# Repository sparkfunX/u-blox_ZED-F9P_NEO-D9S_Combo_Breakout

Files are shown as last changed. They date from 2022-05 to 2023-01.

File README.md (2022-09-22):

# SparkX u-blox ZED-F9P NEO-D9S Combo Breakout

<p align="center">
  <a href="https://github.com/sparkfunX/u-blox_ZED-F9P_NEO-D9S_Combo_Breakout/issues" alt="Issues">
    </a>
  <a href="https://github.com/sparkfunX/u-blox_ZED-F9P_NEO-D9S_Combo_Breakout/actions" alt="Actions">
    </a>
  <a href="https://github.com/sparkfunX/u-blox_ZED-F9P_NEO-D9S_Combo_Breakout/blob/main/LICENSE.md" alt="License">
    </a>
  <a href="https://twitter.com/intent/follow?screen_name=sparkfun">
    </a>
</p>

SparkX u-blox ZED-F9P NEO-D9S Combo Breakout (https://www.sparkfun.com/products/20167)

*[SparkX u-blox ZED-F9P NEO-D9S Combo Breakout (SPX-20167)](https://www.sparkfun.com/products/20167)*

The [SparkX u-blox ZED-F9P NEO-D9S Combo Breakout (SPX-20167)](https://www.sparkfun.com/products/20167) combines the u-blox ZED-F9P multi-band high precision GNSS module
with the NEO-D9S L-band GNSS correction data receiver. With a clear view of the sky, especially a clear view to the South, this combo breakout will deliver centimeter-level
accuracy positioning without needing separate RTK or NTRIP corrections.

The Combo Breakout is designed to work with u-blox's PointPerfect L-band satellite GNSS augmentation service, which provides homogeneous coverage in contiguous USA and Europe.

### Important Note:

u-blox provides products and services to "B2B Customers". Only business customers are eligible to register for a Thingstream (PointPerfect) account. You may be required to demonstrate that the use of the combo breakout is in relation to your trade, business, craft or profession. u-blox products and services are not intended for individual consumer use.

## Repository Contents

* **[/docs](/docs/)** - Online documentation files
    * [board_files](/docs/board_files/) - Files for the product design
        * [Eagle design files](/docs/board_files/ZED-F9P_NEO-D9S_Combo_x02.zip) (.zip)
        * [Schematic](/docs/board_files/Schematic.pdf) (.pdf)
        * [Dimensions](/docs/board_files/Dimensions.png) (.png)
    * [img/hookup_guide/](/docs/img/hookup_guide/) - Images for hookup guide documentation
* **[/Hardware](/Hardware/)** - Eagle design files (.brd, .sch)

## Documentation

* **[Hookup Guide (mkdocs)](https://sparkfunx.github.io/u-blox_ZED-F9P_NEO-D9S_Combo_Breakout)** - Hookup guide for the SparkX u-blox ZED-F9P NEO-D9S Combo Breakout hosted by GitHub pages.

## Product Versions

* [SPX-20167](https://www.sparkfun.com/products/20167) - Initial SparkX Release

## License Information

This product is _**open source**_! 

Please review the LICENSE.md file for license information. 

If you have any questions or concerns on licensing, please contact technical support on our [SparkFun forums](https://forum.sparkfun.com/viewforum.php?f=152).

Distributed as-is; no warranty is given.

- Your friends at SparkFun.

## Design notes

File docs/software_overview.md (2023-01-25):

## Software Overview

There are three key steps to be able to achieve centimeter positioning accuracy using the ZED-F9P NEO-D9S Combo Breakout:

* Register with u-blox Thingstream and sign up for a PointPerfect L-band plan (data stream)
* Configure the NEO-D9S to receive the u-blox PointPerfect correction data stream
* Configure the ZED-F9P with encryption key(s) so it can decrypt and use the correction data

By default, the Combo Breakout is configured such that the correction data is passed from the NEO to the ZED using the UART2 interface.
However, it is also possible to read the correction data from the NEO and push (write) it to the ZED using I<sup>2</sup>C.

## Thingstream and PointPerfect

[Thingstream](https://www.u-blox.com/en/product/thingstream) is u-blox service delivery platform for IoT Communication-as-a-Service, IoT Security-as-a-Service and IoT Location-as-a-Service.

[PointPerfect](https://www.u-blox.com/sites/default/files/PointPerfect_ProductSummary_UBX-21024758.pdf) is u-blox GNSS augmentation service which is designed to provide high-precision GNSS corrections to suitable receivers to provide decimeter-level location accuracy.

PointPerfect data is delivered through Thingstream. The first step is to [register with Thingstream](https://portal.thingstream.io/register) and then request an L-Band plan:

<center>
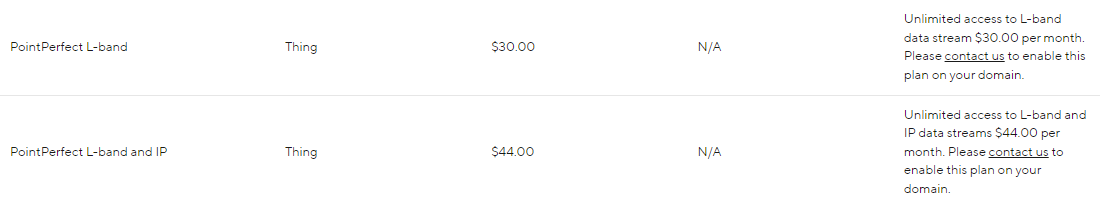
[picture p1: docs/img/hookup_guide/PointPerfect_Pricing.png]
PointPerfect Pricing
<br>
*PointPerfect pricing (correct at Sept. 14th 2022). (Click to enlarge)*
</center>

You can find the current pricing on [u-blox portal](https://portal.thingstream.io/pricing). Select **IoT Location-as-a-Service** and then **PointPerfect**.

You may need to [contact u-blox](mailto:support@thingstream.io) first, to enable the option to purchase an L-Band plan through your Thingstream account.

The **PointPerfect L-band** plan provides unlimited access to the L-band satellite correction data stream (via the NEO-D9S).

If you have an internet connection, you can also receive PointPerfect corrections via IP (MQTT). The **PointPerfect L-band and IP** plan may be a better choice if
you think you may want to receive correction data via both satellite and Internet.

Once L-band permissions are enabled on your Thingstream account, you will be able to add a new L-band Location Thing and view its credentials:

* [Login to Thingstream](https://portal.thingstream.io/)
* Select **Location Services** and then **Location Things**
* The **Add Location Thing** button (top right) will allow you to select and activate an L-Band plan
* Once your L-band plan is active, you will be able to monitor your **Activity** and view your **Credentials** via the appropriate tabs

u-blox have written a [comprehensive application note](https://www.u-blox.com/sites/default/files/documents/NEO-D9S_ZED-F9_Config_SPARTN_AppNote_UBX-22008160.pdf) which
describes in detail: the configuration of both NEO and ZED; and how to interpret the expiry date for the L-band encryption keys. In the following sections, we describe how
to configure the NEO and ZED using our [u-blox GNSS Arduino Library](https://github.com/sparkfun/SparkFun_u-blox_GNSS_v3).

## NEO-D9S Configuration

The first step is to declare the **`SFE_UBLOX_GNSS`** object. Like most Arduino sketches, this is done at a global scope (after the include file declaration), not within the ```setup()``` or ```loop()``` functions. 

```C++
#include <SparkFun_u-blox_GNSS_v3.h> //http://librarymanager/All#SparkFun_u-blox_GNSS_v3
SFE_UBLOX_GNSS myLBand; // NEO-D9S
```

Within ```setup()``` we then need to start (initialize) communiation with the NEO-D9S.
The NEO-D9S has a default I<sup>2</sup>C address of 0x43 and so we need to provide that when calling the ```begin``` method:

```C++
  Wire.begin(); //Start I2C

  while (myLBand.begin(Wire, 0x43) == false) //Connect to the u-blox NEO-D9S using Wire port. The D9S default I2C address is 0x43 (not 0x42)
  {
    Serial.println(F("u-blox NEO-D9S not detected at default I2C address. Please check wiring."));
    delay(2000);
  }
  Serial.println(F("u-blox NEO-D9S connected"));

```

The NEO-D9S needs to be configured so it can receive the PointPerfect correction stream. The configuration items are: 

| Configuration item | Default value |
| :--- | :---- |
| CFG-PMP-CENTER_FREQUENCY | 1539812500 Hz |
| CFG-PMP-SEARCH_WINDOW | 2200 Hz |
| CFG-PMP-USE_SERVICE_ID | 1 (true)|
| CFG-PMP-SERVICE_ID | 50821 |
| CFG-PMP-DATA_RATE | 2400 (B2400) bps |
| CFG-PMP-USE_DESCRAMBLER | 1 (true) |
| CFG-PMP-DESCRAMBLER_INIT | 23560 |
| CFG-PMP-USE_PRESCRAMBLING | 0 (false) |
| CFG-PMP-UNIQUE_WORD | 0xe15ae893e15ae893 |

The centre frequency varies depending on which satellite is broadcasting corrections for your geographical area.
The frequency for the USA is different to that for Europe:

The up-to-date frequencies are distributed via the MQTT **/pp/frequencies/Lb** topic. At the time of writing, they are (in MHz):

```C++
{
  "frequencies": {
    "us": {
      "current": {
        "value": "1556.29"
      }
    },
    "eu": {
      "current": {
        "value": "1545.26"
      }
    }
  }
}
```

We can add those to the code as follows:

```C++
const uint32_t myLBandFreq = 1556290000; // Uncomment this line to use the US SPARTN 1.8 service
//const uint32_t myLBandFreq = 1545260000; // Uncomment this line to use the EU SPARTN 1.8 service
```

The code to configure the NEO-D9S is as follows. Note that the **`UBLOX_CFG_PMP_USE_SERVICE_ID`**, **`UBLOX_CFG_PMP_SERVICE_ID`** and **`UBLOX_CFG_PMP_DESCRAMBLER_INIT`**
also need to be changed.

```C++
  uint8_t ok = myLBand.setVal(UBLOX_CFG_PMP_CENTER_FREQUENCY,  myLBandFreq); // Default 1539812500 Hz
  if (ok) ok = myLBand.setVal(UBLOX_CFG_PMP_SEARCH_WINDOW,     2200);        // Default 2200 Hz
  if (ok) ok = myLBand.setVal(UBLOX_CFG_PMP_USE_SERVICE_ID,    0);           // Default 1 
  if (ok) ok = myLBand.setVal(UBLOX_CFG_PMP_SERVICE_ID,        21845);       // Default 50821
  if (ok) ok = myLBand.setVal(UBLOX_CFG_PMP_DATA_RATE,         2400);        // Default 2400 bps
  if (ok) ok = myLBand.setVal(UBLOX_CFG_PMP_USE_DESCRAMBLER,   1);           // Default 1
  if (ok) ok = myLBand.setVal(UBLOX_CFG_PMP_DESCRAMBLER_INIT,  26969);       // Default 23560
  if (ok) ok = myLBand.setVal(UBLOX_CFG_PMP_USE_PRESCRAMBLING, 0);           // Default 0
  if (ok) ok = myLBand.setVal(UBLOX_CFG_PMP_UNIQUE_WORD,       16238547128276412563ull); // 0xE15AE893E15AE893
```

Finally, we need to ensure that the UART2 port is set correctly. We need to:

* Change the baud rate to 38400 - to match the ZED-F9P's baud rate
* Ensure that the **UBX** protocol is enabled for output on UART2
* Enable the **RXM PMP** message on UART2
    * The **RXM PMP** message contains the **SPARTN** correction data in **UBX** format
* Perform a restart (software reset) so that the NEO-D9S starts using the new configuration items

```C++
  if (ok) ok = myLBand.setVal(UBLOX_CFG_UART2_BAUDRATE,           38400); // match baudrate with ZED default
  if (ok) ok = myLBand.setVal(UBLOX_CFG_UART2OUTPROT_UBX,         1);     // Enable UBX output on UART2
  if (ok) ok = myLBand.setVal(UBLOX_CFG_MSGOUT_UBX_RXM_PMP_UART2, 1);     // Output UBX-RXM-PMP on UART2
  
  Serial.print(F("L-Band configuration: "));
  if (ok)
    Serial.println(F("OK"));
  else
    Serial.println(F("NOT OK!"));

  myLBand.softwareResetGNSSOnly(); // Do a restart
```

Once the NEO-D9S has aquired the signal from the satellite, it will start outputting **PMP** correction messages to the ZED-F9P on UART2.

## ZED-F9P Configuration

We need to declare a second **`SFE_UBLOX_GNSS`** object for the ZED-F9P. Again, this is done at a global scope (after the include file declaration), not within the ```setup()``` or ```loop()``` functions. 

```C++
SFE_UBLOX_GNSS myGNSS; // ZED-F9P
```

Within ```setup()``` we need to start (initialize) communiation with the ZED-F9P:

```C++
  while (myGNSS.begin() == false) //Connect to the u-blox module using Wire port and the default I2C address (0x42)
  {
    Serial.println(F("u-blox GNSS module not detected at default I2C address. Please check wiring."));
    delay(2000);
  }
  Serial.println(F("u-blox GNSS module connected"));
```

We then need to:

* Make sure the ZED-F9P's UART2 port is configured to accept the PMP correction data
* Tell the ZED-F9P to use FIXED carrier solutions when possible (this is the default setting)
* Tell the ZED-F9P to accept L-band PMP as a correction source

```C++
          ok = myGNSS.setI2CInput(COM_TYPE_UBX | COM_TYPE_NMEA | COM_TYPE_SPARTN); //Be sure SPARTN input is enabled
  if (ok) ok = myGNSS.setDGNSSConfiguration(SFE_UBLOX_DGNSS_MODE_FIXED); // Set the differential mode - ambiguities are fixed whenever possible
  if (ok) ok = myGNSS.setVal8(UBLOX_CFG_SPARTN_USE_SOURCE, 1); // use LBAND PMP message
```

The final piece of the puzzle is to provide the ZED-F9P with the keys it needs to decrypt the encrypted SPARTN (PMP) corrections.

The ZED-F9P can hold two dynamic keys: the current key; and the next key. We also need to tell it when each key is valid from, so it knows when to switch to the next key.

You can find the current and next keys in the **`Location Services \ Location Things \ Thing Details \ Credentials`** tab in Thingstream:

<center>
L-band Dynamic Keys<br>
*PointPerfect L-band dynamic keys. (Click to enlarge)*
</center>

The ZED-F9P actually needs to know when the keys are valid **from**, rather than when they expire. Each key is walid for four weeks, so we need to work backwards 4 weeks from the expiry date.

The current key expires at midnight (UTC) at the end of Friday September 23rd. This means it became valid 4 weeks earlier at midnight (UTC) on August 27th:

<center>
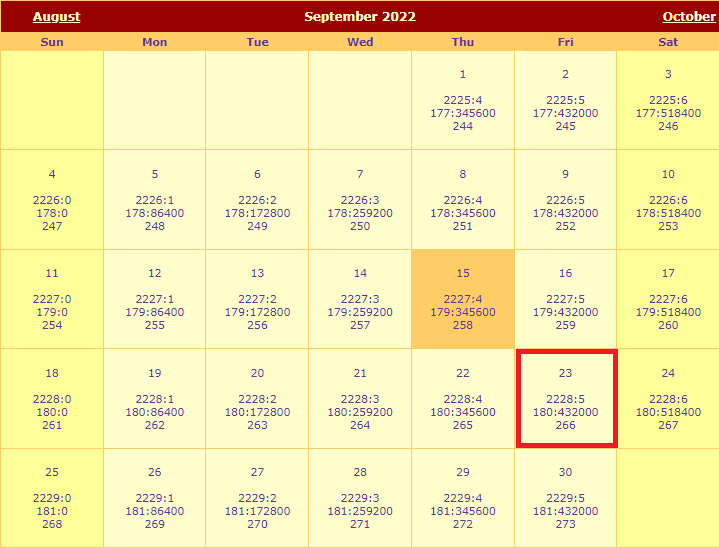
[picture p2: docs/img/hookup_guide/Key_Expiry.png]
Dynamic Key expiry
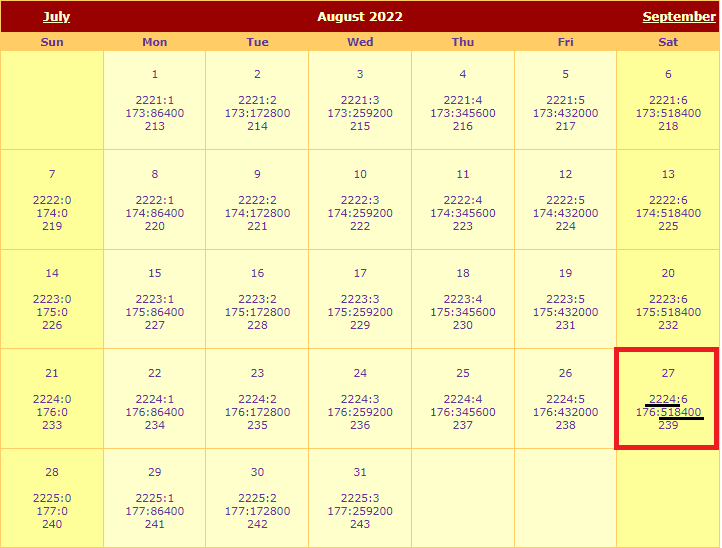
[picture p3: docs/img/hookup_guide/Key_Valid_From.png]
Dynamic Key valid from
  <br>
*Dynamic Key: Expiry and Valid From dates. (Click to enlarge)*
</center>

Using the website recommended in the u-blox Application Note:

**http://navigationservices.agi.com/GNSSWeb**

we can see that the key became valid during GPS week **2224**, at time-of-week **518400**.

We can use the Arduino Library **`setDynamicSPARTNKey`** method to configure a single key:

```C++
  if (ok) ok = myGNSS.setDynamicSPARTNKey(16, 2224, 518400, "500--------------------------177");

  Serial.print(F("GNSS: configuration "));
  if (ok)
    Serial.println(F("OK"));
  else
    Serial.println(F("NOT OK!"));
```

Alternately, we can set both the current key and the next key together using **`setDynamicSPARTNKeys`**. The next key becomes valid during GPS week **2228**:

```C++
  if (ok) ok = myGNSS.setDynamicSPARTNKeys(16, 2224, 518400, "500--------------------------177", 16, 2228, 518400, "582--------------------------a7d");
```

The keys can also be retrieved using MQTT. We have an [Arduino Library example](https://github.com/sparkfun/SparkFun_u-blox_GNSS_v3/tree/main/examples/NEO-D9S_and_NEO-D9C/Example6_PMP_with_L-Band_Keys_via_MQTT)
which shows how to retrieve the keys from the L-band + IP key distribution topic **/pp/ubx/0236/Lb** . That topic provides the keys in UBX (binary) format, ready to be pushed to the ZED.

The keys are also available in human-readable JSON format from the MQTT topic **/pp/key/Lb** . But note that that topic provides the **valid from** in Unix epoch format,
in milliseconds, excluding the 18 leap seconds since GPS time started!

```C++
{
  "dynamickeys": {
    "current": {
      "start": "1661558382000",
      "duration": "2419199999",
      "value": "500--------------------------177"
    },
    "next": {
      "start": "1663977582000",
      "duration": "2419199999",
      "value": "582--------------------------a7d"
    }
  }
}
```

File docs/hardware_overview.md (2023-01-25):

## Hardware Overview

<center>
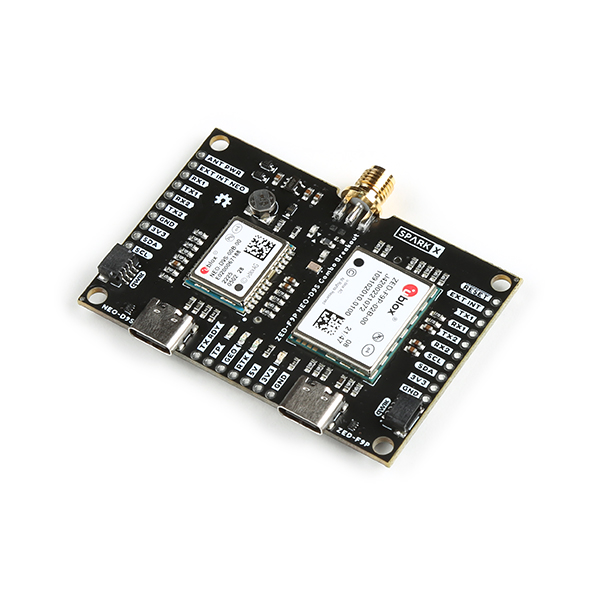
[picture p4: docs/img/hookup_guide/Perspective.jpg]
Combo Breakout PCB
<br>
*The Combo Breakout PCB. (Click to enlarge)*
</center>

The u-blox ZED-F9P NEO-D9S Combo Breakout is a sophisticated yet compact GNSS board. The following is a summary of its features and functions:

* **`ZED-F9P`** - the ZED-F9P is a top-of-the-line module for high accuracy GNSS and GPS location solutions
    * Concurrent reception of GPS, GLONASS, Galileo and BeiDou
    * Multi-band RTK with fast convergence times and reliable performance
    * Centimeter-level accuracy in a small and energy-efficient module

<center>
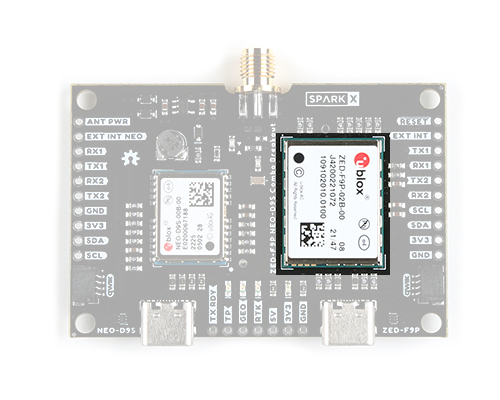
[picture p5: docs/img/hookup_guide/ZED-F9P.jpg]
ZED-F9P
<br>
*The ZED-F9P GNSS module. (Click to enlarge)*
</center>

* **`NEO-D9S`** - the NEO-D9S is a satellite data receiver for L-band correction broadcast
    * The NEO-D9S can be configured for use with a variety of L-band correction services including u-blox's PointPerfect service
    * It decodes the satellite transmission and outputs a correction stream directly to the ZED-F9P via UART2

<center>
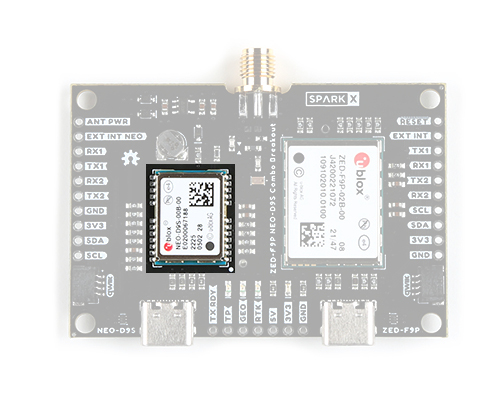
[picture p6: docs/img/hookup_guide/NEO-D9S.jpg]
NEO-D9S
<br>
*The NEO-D9S correction data receiver. (Click to enlarge)*
</center>

* **`UART2 TX and RX`** - the ZED-F9P and NEO-D9S UART2 TX and RX are interconnected (crossed-over) to allow the NEO to feed corrections directly to the ZED
    * The UART2 pins can be isolated if required by opening the **TX2** and **RX2** jumpers
    * Using UART2 to pass the correction data is recommended, but is optional. You can use UART1 or I<sup>2</sup>C instead if you want to. Our u-blox Arduino Library has an [example](https://github.com/sparkfun/SparkFun_u-blox_GNSS_v3/tree/main/examples/NEO-D9S_and_NEO-D9C/Example2_LBand_Corrections_with_NEO-D9S) which shows how to read the correction data from the NEO-D9S and push it to the ZED-F9P using I<sup>2</sup>C.

<center>
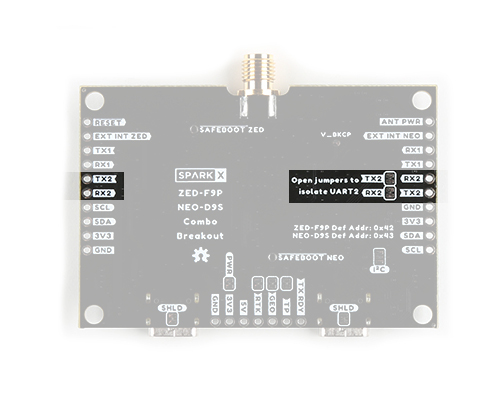
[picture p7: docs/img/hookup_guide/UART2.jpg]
UART2
<br>
*The UART2 connections. (Click to enlarge)*
</center>

* **`Antenna Power Divider`** - the breakout has an on-board power divider (antenna splitter) to divide the satellite signals between the ZED and the NEO
    * The connector is SMA female (standard polarity)
    * 3.3V power is provided for an active antenna

<center>
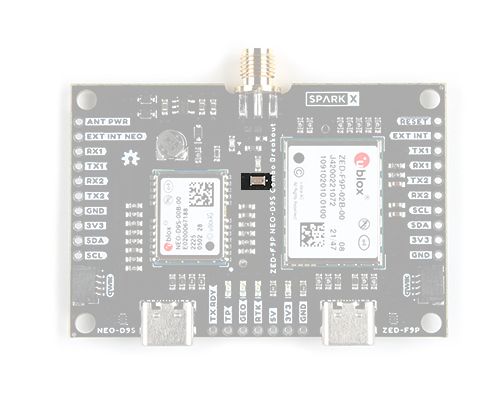
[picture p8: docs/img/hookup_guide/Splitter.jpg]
Splitter
<br>
*The antenna splitter (power divider). (Click to enlarge)*
</center>

* **`Dual USB-C connections`** - one USB-C connector provides a direct connection to the ZED-F9P; the second provides a direct connection to the NEO-D9S
    * The board can be powered via either USB-C connector, or both
    * There is no on-board USB hub. Both ports can be connected simultaneously to the same computer, or different computers if desired

<center>
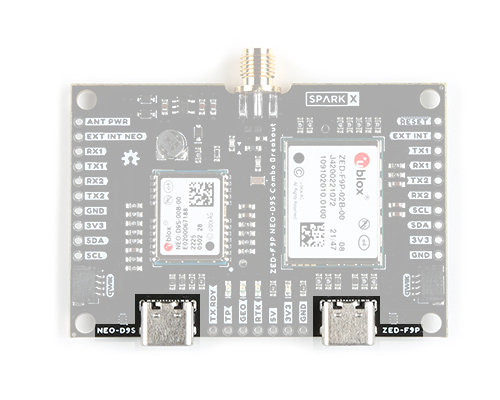
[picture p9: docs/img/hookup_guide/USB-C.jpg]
USB Connectors
<br>
*The two USB-C connectors. (Click to enlarge)*
</center>

* **`LED Indicators`** - the breakout has four LED indicators:
    * **3V3** Power
    * **RTK**: Off = No Carrier Solution; Flashing = Floating Solution; On = Fixed Solution
    * **GEO**: Geofence indication
    * **TP**: Timing Pulse (Pulse Per Second)
    * Each LED can be disabled by opening the corresponding split pad jumper on the bottom of the breakout

<center>
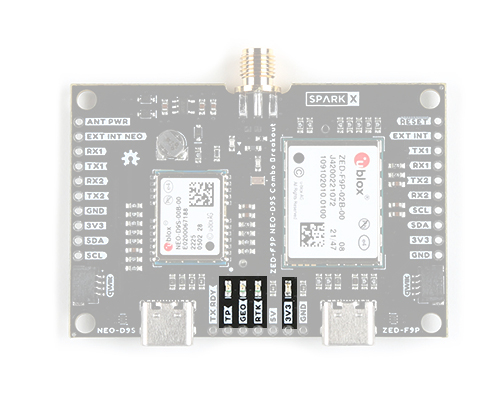
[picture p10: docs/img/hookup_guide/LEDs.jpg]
LEDs
<br>
*The LEDs. (Click to enlarge)*
</center>

* **`Dual Qwiic Connectors`** - the breakout has two Qwiic (I<sup>2</sup>C) connectors allowing the breakout to be daisy-chained into your Qwiic project

<center>
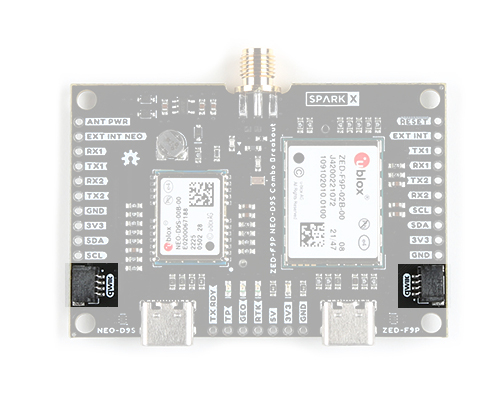
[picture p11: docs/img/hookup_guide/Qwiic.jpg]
Qwiic Connectors
<br>
*The two Qwiic connectors. (Click to enlarge)*
</center>

* **`Back-up Battery`** - a small rechargeable coin cell maintains the ZED-F9P battery-backed RAM while the power is disconnected

<center>
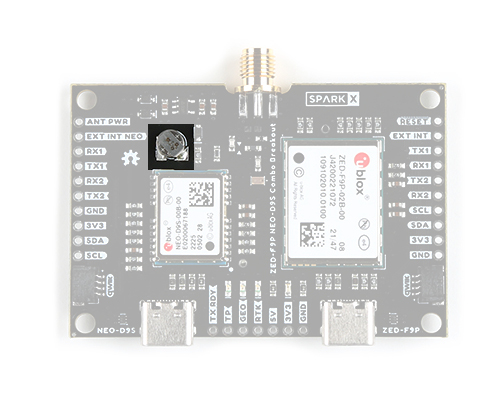
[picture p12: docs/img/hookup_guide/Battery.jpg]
Back-up Battery
<br>
*The rechargeable back-up battery. (Click to enlarge)*
</center>

* **`Full set of breakout pads`** - the breakout pads provide full access to the ZED-F9P and NEO-D9S pins 
    * I<sup>2</sup>C
    * UART1
    * UART2
    * External Interrupt
    * Reset
    * Safeboot
    * ZED-F9P: TX_RDY, TP, GEO, RTK
    * Power: 5V and 3.3V

<center>
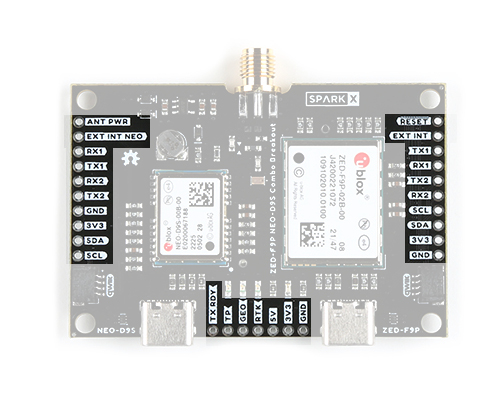
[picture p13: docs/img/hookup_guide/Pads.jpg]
Breakout Pads
<br>
*The breakout pads. (Click to enlarge)*
</center>

## Board Dimensions

The board dimensions are illustrated in the drawing below. The listed measurements are in inches. The four mounting holes are compatible with 4-40 UNC or M3.0 screws.

<center>
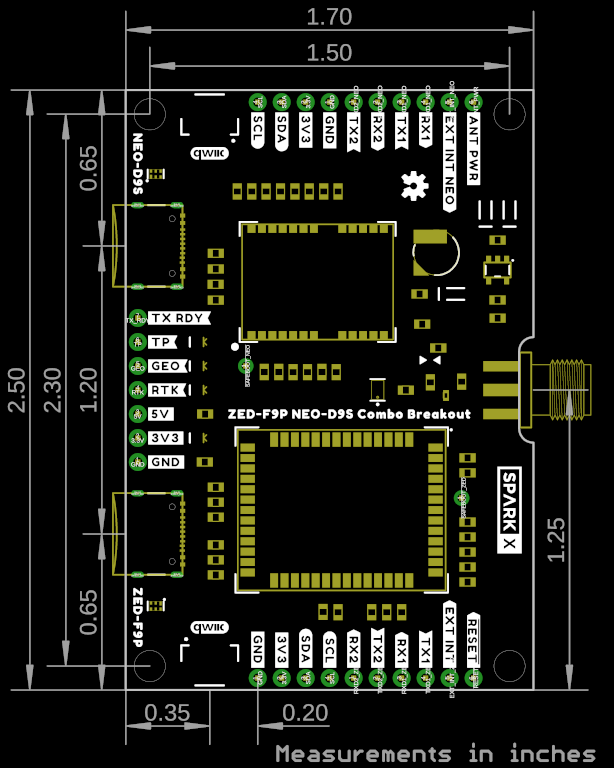
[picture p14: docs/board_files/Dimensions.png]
Board Dimensions
<br>
*Board dimensions. (Click to enlarge)*
</center>

## Left Edge Breakout Pads

With the SMA connector oriented to the 'top', the breakout pads down the left side of the board are:

<table style="font-size:12.25px; width:100%">
    <tr>
        <th style="text-align:center; vertical-align:middle; min-width:1rem;" width="20.0%">
            Pad
        </th>
        <th style="text-align:center; vertical-align:middle; min-width:4rem;" width="80.0%">
            Function
        </th>
    </tr>
    <tr>
        <td style="vertical-align:middle" align="center"><b>ANT_PWR</b></td>
        <td style="vertical-align:middle" align="center">External antenna power<br>Cut the <b>ANT_VCC</b> trace and install L1 to enable</td>
    </tr>
    <tr>
        <td style="vertical-align:middle" align="center"><b>EXT_INT_NEO</b></td>
        <td style="vertical-align:middle" align="center">Connected to the NEO-D9S EXT_INT pin</td>
    </tr>
    <tr>
        <td style="vertical-align:middle" align="center"><b>RX1</b></td>
        <td style="vertical-align:middle" align="center">NEO-D9S UART1 RX Pin</td>
    </tr>
    <tr>
        <td style="vertical-align:middle" align="center"><b>TX1</b></td>
        <td style="vertical-align:middle" align="center">NEO-D9S UART1 TX Pin</td>
    </tr>
    <tr>
        <td style="vertical-align:middle" align="center"><b>RX2</b></td>
        <td style="vertical-align:middle" align="center">NEO-D9S UART2 RX Pin<br>Connected to ZED-F9P TX2 (Open the <b>TX2</b> jumper to isolate)</td>
    </tr>
    <tr>
        <td style="vertical-align:middle" align="center"><b>TX2</b></td>
        <td style="vertical-align:middle" align="center">NEO-D9S UART2 TX Pin<br>Connected to ZED-F9P RX2 (Open the <b>RX2</b> jumper to isolate)</td>
    </tr>
    <tr>
        <td style="vertical-align:middle" align="center"><b>GND</b></td>
        <td style="vertical-align:middle" align="center">Power Ground (0V)</td>
    </tr>
    <tr>
        <td style="vertical-align:middle" align="center"><b>3V3</b></td>
        <td style="vertical-align:middle" align="center">3.3V Supply rail<br>Output of regulator U2 (Can also be used as a power input)</td>
    </tr>
    <tr>
        <td style="vertical-align:middle" align="center"><b>SDA</b></td>
        <td style="vertical-align:middle" align="center">I<sup>2</sup>C Data<br>Common to both ZED and NEO</td>
    </tr>
    <tr>
        <td style="vertical-align:middle" align="center"><b>SCL</b></td>
        <td style="vertical-align:middle" align="center">I<sup>2</sup>C Clock<br>Common to both ZED and NEO</td>
    </tr>
</table>

*For more details, users can reference the [schematic](./board_files/Schematic.pdf).*

## Right Edge Breakout Pads

With the SMA connector oriented to the 'top', the breakout pads down the right side of the board are:

<table style="font-size:12.25px; width:100%">
    <tr>
        <th style="text-align:center; vertical-align:middle; min-width:1rem;" width="20.0%">
            Pad
        </th>
        <th style="text-align:center; vertical-align:middle; min-width:4rem;" width="80.0%">
            Function
        </th>
    </tr>
    <tr>
        <td style="vertical-align:middle" align="center"><b>RESET</b></td>
        <td style="vertical-align:middle" align="center">Reset<br>Active low. Common to both ZED and NEO</td>
    </tr>
    <tr>
        <td style="vertical-align:middle" align="center"><b>EXT_INT</b></td>
        <td style="vertical-align:middle" align="center">Connected to the ZED-F9P EXT_INT pin</td>
    </tr>
    <tr>
        <td style="vertical-align:middle" align="center"><b>TX1</b></td>
        <td style="vertical-align:middle" align="center">ZED-F9P UART1 TX Pin</td>
    </tr>
    <tr>
        <td style="vertical-align:middle" align="center"><b>RX1</b></td>
        <td style="vertical-align:middle" align="center">ZED-F9P UART1 RX Pin</td>
    </tr>
    <tr>
        <td style="vertical-align:middle" align="center"><b>TX2</b></td>
        <td style="vertical-align:middle" align="center">ZED-F9P UART2 TX Pin<br>Connected to NEO-D9S RX2 (Open the <b>TX2</b> jumper to isolate)</td>
    </tr>
    <tr>
        <td style="vertical-align:middle" align="center"><b>RX2</b></td>
        <td style="vertical-align:middle" align="center">ZED-F9P UART2 RX Pin<br>Connected to NEO-D9S TX2 (Open the <b>RX2</b> jumper to isolate)</td>
    </tr>
    <tr>
        <td style="vertical-align:middle" align="center"><b>SCL</b></td>
        <td style="vertical-align:middle" align="center">I<sup>2</sup>C Clock<br>Common to both ZED and NEO</td>
    </tr>
    <tr>
        <td style="vertical-align:middle" align="center"><b>SDA</b></td>
        <td style="vertical-align:middle" align="center">I<sup>2</sup>C Data<br>Common to both ZED and NEO</td>
    </tr>
    <tr>
        <td style="vertical-align:middle" align="center"><b>3V3</b></td>
        <td style="vertical-align:middle" align="center">3.3V Supply rail<br>Output of regulator U2 (Can be used as a power input)</td>
    </tr>
    <tr>
        <td style="vertical-align:middle" align="center"><b>GND</b></td>
        <td style="vertical-align:middle" align="center">Power Ground (0V)</td>
    </tr>
</table>

*For more details, users can reference the [schematic](./board_files/Schematic.pdf).*

## Right Edge Breakout Pads

With the SMA connector oriented to the 'top', the breakout pads along the bottom edge of the board are:

<table style="font-size:12.25px; width:100%">
    <tr>
        <th style="text-align:center; vertical-align:middle; min-width:1rem;" width="20.0%">
            Pad
        </th>
        <th style="text-align:center; vertical-align:middle; min-width:4rem;" width="80.0%">
            Function
        </th>
    </tr>
    <tr>
        <td style="vertical-align:middle" align="center"><b>TX_RDY</b></td>
        <td style="vertical-align:middle" align="center">Indicates the ZED-F9P has data waiting in its I<sup>2</sup>C TX buffer</td>
    </tr>
    <tr>
        <td style="vertical-align:middle" align="center"><b>TP</b></td>
        <td style="vertical-align:middle" align="center">ZED-F9P Timing Pulse (Pulse Per Second)</td>
    </tr>
    <tr>
        <td style="vertical-align:middle" align="center"><b>GEO</b></td>
        <td style="vertical-align:middle" align="center">ZED-F9P Geofence indicator</td>
    </tr>
    <tr>
        <td style="vertical-align:middle" align="center"><b>RTK</b></td>
        <td style="vertical-align:middle" align="center">ZED-F9P RTK indication<br>High = No Carrier Solution. Square Wave = Floating Solution. Low = Fixed Solution</td>
    </tr>
    <tr>
        <td style="vertical-align:middle" align="center"><b>5V</b></td>
        <td style="vertical-align:middle" align="center">5V Power Rail<br>Can be used as a power input or output (from USB) (Diode protected)</td>
    </tr>
    <tr>
        <td style="vertical-align:middle" align="center"><b>3V3</b></td>
        <td style="vertical-align:middle" align="center">3.3V Supply rail<br>Output of regulator U2 (Can be used as a power input)</td>
    </tr>
    <tr>
        <td style="vertical-align:middle" align="center"><b>GND</b></td>
        <td style="vertical-align:middle" align="center">Power Ground (0V)</td>
    </tr>
</table>

*For more details, users can reference the [schematic](./board_files/Schematic.pdf).*

## Jumpers

!!! note
    <p>Never modified a jumper before? Check out our <a href="https://learn.sparkfun.com/tutorials/664">Jumper Pads and PCB Traces tutorial</a> for a quick introduction!</p>
    <p align="center">
        <a href="https://learn.sparkfun.com/tutorials/664">How to Work with Jumper Pads and PCB Traces<br>
        </a>
    </p>

There are multiple jumpers on the back of the board that can be used to modify how the board functions.

<center>
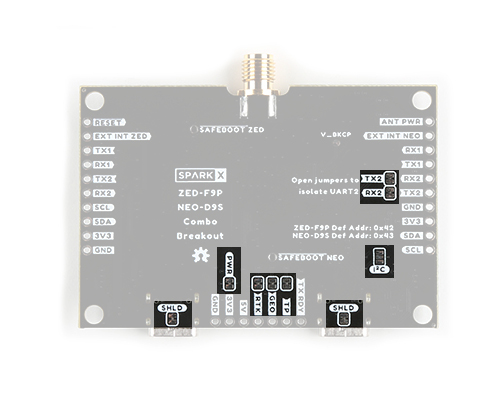
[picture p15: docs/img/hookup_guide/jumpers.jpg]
Jumpers
<br>
*The jumpers on the back of the function board. (Click to enlarge)*
</center>

* **TX2** - open this jumper to isolate NEO-D9S RX2 from ZED-F9P TX2
* **RX2** - open this jumper to isolate NEO-D9S TX2 from ZED-F9P RX2
    * By default, the NEO-D9S PMP (SPARTN) correction data stream is output directly from NEO-D9S TX2 to the ZED-F9P RX2
    * Opening this jumper will break that connection
    * Correction data can be read from the NEO-D9S and pushed to the ZED-F9P via I<sup>2</sup>C instead
* **I<sup>2</sup>C** - close this double jumper to connect additional pull-up resistors to I<sup>2</sup>C **SCL** and **SDA**. Not recommended
* **SHLD** - the two **SHLD** jumpers can be opened to isolate the USB-C connector shields from **GND**. Not recommended, but may help prevent EMI
* **PWR** - open this jumper to disable the Power LED
* **RTK** - open this jumper to disable the RTK LED
* **GEO** - open this jumper to disable the GEO LED
* **TP** - open this jumper to disable the TP (PPS) LED

## ANT PWR

By default, 3.3V active antenna power is provided on the SMA connector via the NEO-D9S **VCC_RF** output pin.
Power is delivered via a 10 Ohm resistor, to limit the current in case the antenna cable becomes shorted.

If your antenna requires a higher voltage (or current):

* Isolate **VCC_RF** by cutting the trace marked by the arrow symbols on the top of the PCB

<center>
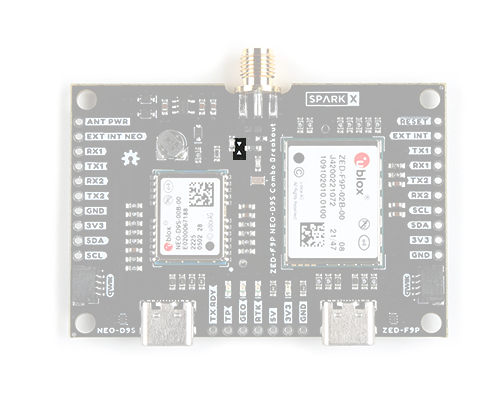
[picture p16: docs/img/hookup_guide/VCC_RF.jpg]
VCC_RF
<br>
*The VCC_RF trace. (Click to enlarge)*
</center>

* Install inductor L1 - using a 0603 inductor with impedance >500 Ohms at 1.5 GHz

<center>
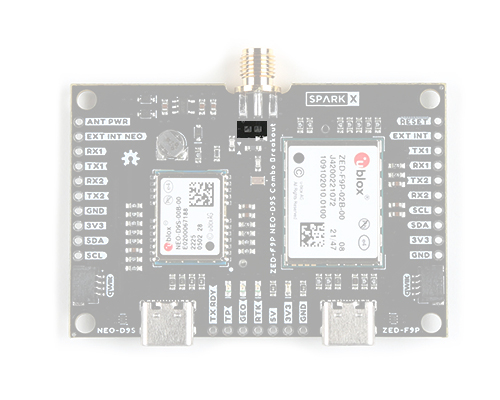
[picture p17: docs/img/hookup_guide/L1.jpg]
L1
<br>
*The position of L1. (Click to enlarge)*
</center>

* Inject a **clean** DC supply voltage between the **ANT PWR** breakout pad and **GND**

## SAFEBOOT

It _may_ be necessary to place the ZED-F9P or NEO-D9S into a "safe boot" state before applying a firmware upgrade.

If this becomes necessary:

* Disconnect power to the breakout board
* For the ZED-F9P: connect a jumper wire between the **SAFEBOOT ZED** test point and **GND**
* Reconnect the power
* Disconnect the jumper
* Upgrade the firmware using u-center

Repeat for the NEO-D9S using the **SAFEBOOT NEO** test point.

<center>
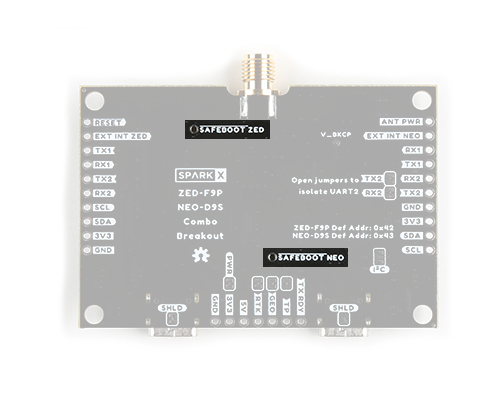
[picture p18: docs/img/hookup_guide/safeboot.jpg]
<br>
*The two SAFEBOOT test points. (Click to enlarge)*
</center>

## LED Indicators

The breakout has four LED indicators:

* **3V3** Power
* **RTK**: Off = No Carrier Solution; Flashing = Floating Solution; On = Fixed Solution
* **GEO**: Geofence indication
* **TP**: Timing Pulse (Pulse Per Second)

Each LED can be disabled by opening the corresponding split pad jumper on the bottom of the breakout

## Back-up Battery

A small rechargeable coin cell maintains the ZED-F9P battery-backed RAM while the power is disconnected. It maintains the ZED's GNSS Almanac and Real Time Clock.

The battery is recharged slowly whenever 3.3V power is present.

If the battery becomes discharged, connect 3.3V power for at least 48 hours to recharge the battery.

## Power Supply and I/O voltage

Both the ZED-F9P and NEO-D9S are 3.3V devices. They operate from 3.3V and all of their I/O pins are 3.3V.

!!! attention
    Do not drive any of the ZED-F9P or NEO-D9S I/O pins using 5V signals. You may damage either or both modules if you do. Use a suitable level-shifter if you want to interface to a 5V development board.

The board has a 3.3V regulator on-board to regulate 5V USB-C power (if present) down to 3.3V.

The options for providing power to the board are as follows:

* 5V power via one or both USB-C ports
    * Diode protection is provided
* 5V power via the **5V** breakout pin
    * Diode protection prevents the USB-C ports from being reverse-fed
* 3.3V power via:
    * Either of the Qwiic connectors
    * Any of the **3V3** breakout pins

## Current Draw

Worst-case current draw of the ZED-F9P and NEO-D9S combined is 260mA at 3.3V.

Typical current draw of the ZED-F9P and NEO-D9S combined is 100mA.

(These figures exclude any current drawn by an active antenna.)

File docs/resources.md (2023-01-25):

# Resources

For more resources related to the SparkX u-blox ZED-F9P NEO-D9S Combo Breakout, check out the links listed here: 

* [Schematic](./board_files/Schematic.pdf) (PDF)
* [Eagle Files](./board_files/ZED-F9P_NEO-D9S_Combo_x02.zip) (ZIP)
* [Board Dimensions](./board_files/Dimensions.png) (PNG)
* [SparkFun u-blox GNSS Arduino Library](https://github.com/sparkfun/SparkFun_u-blox_GNSS_v3)
    * [Example: L-Band correction with correction data push via I<sup>2</sup>C](https://github.com/sparkfun/SparkFun_u-blox_GNSS_v3/tree/main/examples/NEO-D9S_and_NEO-D9C/Example2_LBand_Corrections_with_NEO-D9S). The I<sup>2</sup>C push is not necessary on the combo breakout. The correction data will be transferred automatically via UART2.
    * [Example: L-Band correction with key retrieval via MQTT](https://github.com/sparkfun/SparkFun_u-blox_GNSS_v3/tree/main/examples/NEO-D9S_and_NEO-D9C/Example6_PMP_with_L-Band_Keys_via_MQTT)

u-blox resources: 

* [NEO-D9S and ZED-F9 configuration - SPARTN L-band correction data reception](https://www.u-blox.com/sites/default/files/documents/NEO-D9S_ZED-F9_Config_SPARTN_AppNote_UBX-22008160.pdf)
* [u-blox u-center - GNSS evaluation software for Windows](https://www.u-blox.com/en/product/u-center)
* [PointPerfect GNSS augmentation service](https://www.u-blox.com/en/product/pointperfect)
* [PointPerfect Product Summary](https://www.u-blox.com/sites/default/files/PointPerfect_ProductSummary_UBX-21024758.pdf)
* [PointPerfect Service Description](https://developer.thingstream.io/guides/location-services/pointperfect-service-description)
* [PointPerfect Service Coverage](https://developer.thingstream.io/guides/location-services/pointperfect-service-description#h.jv0o1vz2wkn3)
* [Thingstream IoT service delivery platform](https://www.u-blox.com/en/product/thingstream)
* [Thingstream Login](https://portal.thingstream.io/)
* [Thingstream Registration](https://portal.thingstream.io/register)

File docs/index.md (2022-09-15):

<p align="center">
  <a href="https://github.com/sparkfunX/u-blox_ZED-F9P_NEO-D9S_Combo_Breakout/issues" alt="Issues">
    </a>
  <a href="https://github.com/sparkfunX/u-blox_ZED-F9P_NEO-D9S_Combo_Breakout/actions" alt="Actions">
    </a>
  <a href="https://github.com/sparkfunX/u-blox_ZED-F9P_NEO-D9S_Combo_Breakout/blob/main/LICENSE.md" alt="License">
    </a>
  <a href="https://twitter.com/intent/follow?screen_name=sparkfun">
    </a>
</p>

# SparkX u-blox ZED-F9P NEO-D9S Combo Breakout

The [SparkX u-blox ZED-F9P NEO-D9S Combo Breakout (SPX-20167)](https://www.sparkfun.com/products/20167) combines the u-blox ZED-F9P multi-band high precision GNSS module
with the NEO-D9S L-band GNSS correction data receiver. With a clear view of the sky, especially a clear view to the South, this combo breakout will deliver centimeter-level
accuracy positioning without needing separate RTK or NTRIP corrections. An on-board splitter (power divider) allows you to connect both modules to a single L1/L2/L-Band antenna.

<center>
SparkX u-blox ZED-F9P NEO-D9S Combo Breakout (https://www.sparkfun.com/products/20167)
<br>
### [SparkX u-blox ZED-F9P NEO-D9S Combo Breakout (SPX-20167)](https://www.sparkfun.com/products/20167)
</center>

The Combo Breakout is designed to work with u-blox's PointPerfect L-band satellite GNSS augmentation service, which provides homogeneous coverage in contiguous USA and Europe.

!!! attention
    u-blox provides products and services to "B2B Customers". Only business customers are eligible to register for a Thingstream (PointPerfect) account. You may be required to demonstrate that the use of the combo breakout is in relation to your trade, business, craft or profession. u-blox products and services are not intended for individual consumer use.

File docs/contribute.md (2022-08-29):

# Contribute: Help Fix our Mistake!

Spot something wrong? Feel free to contribute our open-source design and documentation. 

## Improve our Documentation

All of this documentation can be modified by you! Please help us make it better.

* These pages are contained in the [`docs` folder](https://github.com/sparkfunX/u-blox_ZED-F9P_NEO-D9S_Combo_Breakout/tree/main/docs) of the [SparkX u-blox ZED-F9P NEO-D9S Combo Breakout](https://github.com/sparkfunX/u-blox_ZED-F9P_NEO-D9S_Combo_Breakout) repository.

### Submit a Correction

1. Fork this repo
2. Add your corrections or improvements to the markdown file
3. File a pull request with your changes, and enjoy making the ~~words~~ ~~worlds~~ world a better place.
    * Once received, the documentation specialist will automatically be notified.
    * We will review your suggested improvements to make sure they are correct and fit within our documentation standards.

## Improve our Hardware Design

All of our designs are open-source! Please help us make it better.

* Our board design files are contained in the [`Hardware` folder](https://github.com/sparkfunX/u-blox_ZED-F9P_NEO-D9S_Combo_Breakout/tree/main/Hardware) of the [SparkX u-blox ZED-F9P NEO-D9S Combo Breakout](https://github.com/sparkfunX/u-blox_ZED-F9P_NEO-D9S_Combo_Breakout) repository. 

### Submit a Design Improvement

1. Fork this repo
2. Add your design improvements
3. File a pull request with your changes, and enjoy making the ~~words~~ ~~worlds~~ world a better place.
    * Once received, the engineer in charge of the original design will automatically be notified.
    * We will review your suggested improvements, if they are within our board design standards and meet our product design requirements, we will flag these changes for our next board revision. *(Please note, that even if your suggestion is accepted, these changes may not be immediate. We may have to cycle through our current product inventory first.)*

## Contributors

Let's provided some recognition to the contributors for this project!

GitHub Contributors Image
<br>


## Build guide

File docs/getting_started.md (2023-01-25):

## Getting Started

Before you begin, you need to think about how you will use the SparkX u-blox ZED-F9P NEO-D9S Combo Breakout.

The Combo Breakout is a very versatile board, combining the u-blox ZED-F9P multi-band high precision GNSS module with the NEO-D9S L-band GNSS correction data receiver.

<center>
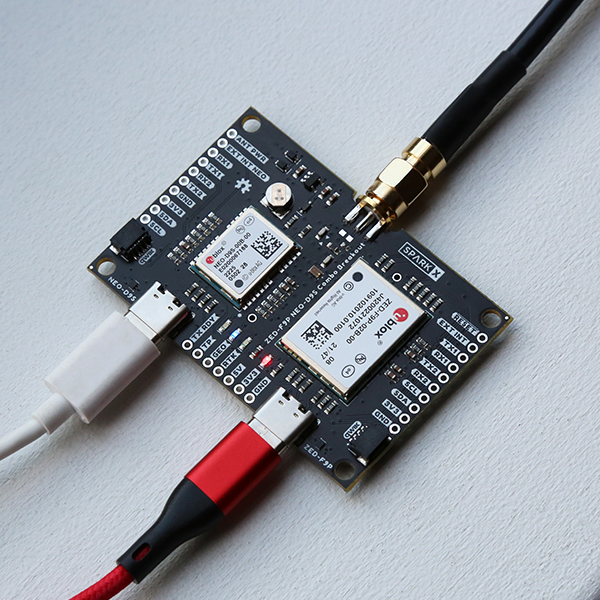
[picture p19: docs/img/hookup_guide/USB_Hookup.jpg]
Hookup for u-center with two USB cables
<br>
*Hookup for u-center with two USB cables. (Click to enlarge)*
</center>

If you intend to use [u-blox's u-center (GNSS evaluation software for Windows)](https://www.u-blox.com/en/product/u-center) to configure both the ZED-F9P and the NEO-D9S
and log data from the ZED-F9P, all you need to get started is a pair of USB cables and a suitable antenna. u-blox have written an
[excellent application note](https://www.u-blox.com/sites/default/files/documents/NEO-D9S_ZED-F9_Config_SPARTN_AppNote_UBX-22008160.pdf) which shows how to configure both modules using u-center.

<table style="border-style:none">
    <tr>
        <td>
            <a href="https://www.sparkfun.com/products/17751">
                <center>GNSS Multi-Band L1/L2 Surveying Antenna (TNC) - TOP106</center>
                <h3 class="title">GNSS Multi-Band L1/L2 Surveying Antenna (TNC) - TOP106</h3>
            </a>
            GPS-17751
        </td>
        <td>
            <a href="https://www.sparkfun.com/products/21281">
                <center>Interface Cable - SMA Female to SMA Male (10m, RG58)
                </center>
                <h3 class="title">Interface Cable - SMA Female to SMA Male (10m, RG58)</h3>
            </a>
            CAB-21281
        </td>
    </tr>
</table>

The Combo Breakout has a single female SMA socket for the antenna connection. An on-board splitter (power divider) allows the ZED-F9P and NEO-D9S to share a single antenna. You need an antenna which supports both L1 and L2 GNSS, and which also provides broad coverage of the L-Band for the correction signal. Our TOP-106 antenna is a good choice. It has a TNC connection,
so you may also want to purchase a SMA to TNC interface cable and/or a SMA female to male extension cable, depending on your needs:

<table style="border-style:none">
    <tr>
        <td>
            <a href="https://www.sparkfun.com/products/17833">
                <center>Interface Cable - SMA Male to TNC Male (300mm)</center>
                <h3 class="title">Interface Cable - SMA Male to TNC Male (300mm)</h3>
            </a>
            CAB-17833
        </td>
        <td>
            <a href="https://www.sparkfun.com/products/12861">
                <center>Interface Cable - SMA Female to SMA Male (25cm)
                </center>
                <h3 class="title">Interface Cable - SMA Female to SMA Male (25cm)</h3>
            </a>
            WRL-12861
        </td>
    </tr>
</table>

## Getting Started with Arduino

<center>
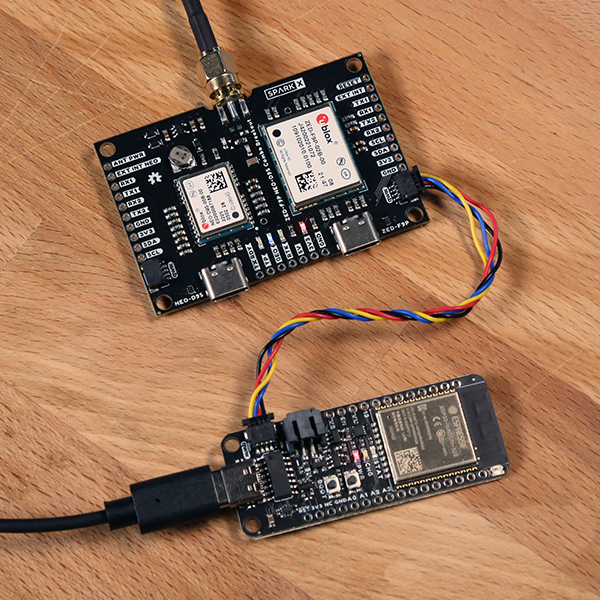
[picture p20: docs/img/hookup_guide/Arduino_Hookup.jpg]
Hookup for Arduino using Qwiic
<br>
*Hookup for Arduino using Qwiic. (Click to enlarge)*
</center>

It is also possible to power the board and communicate with it using I<sup>2</sup>C by connecting to either of the board's **Qwiic** connectors.
SparkFun's [Qwiic Connect System](https://www.sparkfun.com/qwiic) uses 4-pin JST connectors, allowing you to quickly interface your development board to the Combo Board.

Our [u-blox GNSS Arduino Library - v3](https://github.com/sparkfun/SparkFun_u-blox_GNSS_v3) contains a comprehensive set of tried and tested examples that will work
on any Qwiic-enabled development board. There are dedicated examples for the ZED-F9P and NEO-D9S.

You can also use 3.3V Serial (UART) to communicate with both the ZED-F9P and NEO-D9S. Our Arduino Library supports both Serial and I<sup>2</sup>C. (It supports SPI too, but SPI
is not supported on the Combo Breakout).

When choosing a development board, you might want to choose one which has built-in WiFi. The correction data received by the NEO-D9S is encrypted, you need to pass keys to the
ZED-F9P so it can decrypt the data. A WiFi connection will allow you to download the PointPerfect SPARTN encryption keys directly from u-blox's Thingstream IoT service using MQTT.

You might also find a microSD card socket useful for data logging. If you want to log data while you are out in the field, being able to connect a Li-Po battery will be useful too.

These two ESP32 development boards support: Qwiic, Serial, WiFi, microSD and Li-Po.

<table style="border-style:none">
    <tr>
        <td>
            <a href="https://www.sparkfun.com/products/20168">
                <center>SparkFun Thing Plus - ESP32 WROOM (USB-C)</center>
                <h3 class="title">SparkFun Thing Plus - ESP32 WROOM (USB-C)</h3>
            </a>
            WRL-20168
        </td>
        <td>
            <a href="https://www.sparkfun.com/products/19177">
                <center>SparkFun IoT RedBoard - ESP32 Development Board
                </center>
                <h3 class="title">SparkFun IoT RedBoard - ESP32 Development Board</h3>
            </a>
            WRL-19177
        </td>
    </tr>
    <tr>
        <td>
            <a href="https://www.sparkfun.com/products/15081">
                <center>SparkFun Qwiic Cable Kit</center>
                <h3 class="title">SparkFun Qwiic Cable Kit</h3>
            </a>
            KIT-15081
        </td>
        <td>
            <a href="https://www.sparkfun.com/products/14743">
                <center>USB 3.1 Cable A to C - 3 Foot
                </center>
                <h3 class="title">USB 3.1 Cable A to C - 3 Foot</h3>
            </a>
            CAB-14743
        </td>
    </tr>
</table>

## Li-Po Battery
<p>For mobile applications, users will want to pick up a <a href="https://www.sparkfun.com/categories/54">single-cell LiPo battery</a> from our catalog. Below, are a few available options:</p>

<table style="border-style:none">
    <tr>
        <td>
            <a href="https://www.sparkfun.com/products/13855">
                <center>Lithium Ion Battery - 2Ah</center>
                <h3 class="title">Lithium Ion Battery - 2Ah</h3>
            </a>
            PRT-13855
        </td>
        <td>
            <a class="thumb" href="https://www.sparkfun.com/products/13851">
                <center>Lithium Ion Battery - 400mAh
                </center>
                <h3 class="title">Lithium Ion Battery - 400mAh</h3>
            </a>
            PRT-13851
        </td>
        <td>
            <a class="thumb" href="https://www.sparkfun.com/products/13813">
                <center>Lithium Ion Battery - 1Ah
                </center>
                <h3 class="title">Lithium Ion Battery - 1Ah</h3>
            </a>
            PRT-13813
        </td>
    </tr>
</table>

## Jumper Modification

<p>To modify the jumpers, users will need <a href="https://www.sparkfun.com/categories/49">soldering equipment</a> and/or a <a href="https://www.sparkfun.com/categories/379">knife</a>.</p>

<table style="border-style:none">
    <tr>
        <td>
            <a href="https://www.sparkfun.com/products/9325">
                <center>Solder Lead Free - 100-gram Spool</center>
                <h3 class="title">Solder Lead Free - 100-gram Spool</h3>
            </a>
            TOL-09325
        </td>
        <td>
            <a class="thumb" href="https://www.sparkfun.com/products/14228">
                <center>Weller WLC100 Soldering Station
                </center>
                <h3 class="title">Weller WLC100 Soldering Station</h3>
            </a>
            TOL-14228
        </td>
        <td>
            <a class="thumb" href="https://www.sparkfun.com/products/14579">
                <center>Chip Quik No-Clean Flux Pen - 10mL
                </center>
                <h3 class="title">Chip Quik No-Clean Flux Pen - 10mL</h3>
            </a>
            TOL-14579
        </td>
        <td>
            <a class="thumb" href="https://www.sparkfun.com/products/9200">
                <center>Hobby Knife
                </center>
                <h3 class="title">Hobby Knife</h3>
            </a>
            TOL-09200
        </td>
    </tr>
</table>

!!! note
    <p>New to jumpter pads? Check out our <a href="https://learn.sparkfun.com/tutorials/664">Jumper Pads and PCB Traces Tutorial</a> for a quick introduction!</p>
    <p align="center">
        <a href="https://learn.sparkfun.com/tutorials/664">How to Work with Jumper Pads and PCB Traces<br>
        </a>
    </p>

## Suggested Reading

As a more professionally oriented product, we will skip over the more fundamental tutorials (i.e. [**Ohm's Law**](https://learn.sparkfun.com/tutorials/voltage-current-resistance-and-ohms-law) and [**What is Electricity?**](https://learn.sparkfun.com/tutorials/what-is-electricity)). However, below are a few tutorials that may help users familiarize themselves with various aspects of the board.

<table style="border-style:none">
    <tr>
        <td align="center">
            <a href="https://learn.sparkfun.com/tutorials/61">Installing the Arduino IDE<br>
            </a>
        </td>
        <td align="center">
            <a href="https://learn.sparkfun.com/tutorials/1265">Installing Board Definitions in the Arduino IDE<br>
            </a>
        </td>
        <td align="center">
            <a href="https://learn.sparkfun.com/tutorials/12">Installing an Arduino Library<br>
            </a>
        </td>
    </tr>
    <tr>
        <td align="center">
            <a href="https://learn.sparkfun.com/tutorials/908">How to Install CH340 Drivers<br>
            </a>
        </td>
        <td align="center">
            <a href="https://learn.sparkfun.com/tutorials/5">How to Solder: Through-Hole Soldering<br>
            </a>
        </td>
        <td align="center">
            <a href="https://learn.sparkfun.com/tutorials/664">How to Work with Jumper Pads and PCB Traces<br>
            </a>
        </td>
    </tr>
    <tr>
        <td align="center">
            <a href="https://learn.sparkfun.com/tutorials/8">Serial Communication<br>
            </a>
        </td>
        <td align="center">
            <a href="https://learn.sparkfun.com/tutorials/89">Analog vs. Digital<br>
            </a>
        </td>
        <td align="center">
            <a href="https://learn.sparkfun.com/tutorials/51">Pulse Width Modulation<br>
            </a>
        </td>
    </tr>
    <tr>
        <td align="center">
            <a href="https://learn.sparkfun.com/tutorials/62">Logic Levels<br>
            </a>
        </td>
        <td align="center">
            <a href="https://learn.sparkfun.com/tutorials/82">I2C<br>
            </a>
        </td>
        <td align="center">
            <a href="https://learn.sparkfun.com/tutorials/16">Serial Peripheral Interface (SPI)<br>
            </a>
        </td>
    </tr>
</table>

<center>
<div align="center">
    <div style="top:5px;left:5px;background-color:Gray;position:relative">
        <div style="top:-5px;left:-5px;background-color:#ffffff;position:relative;border:1px solid black;">
            <a href="https://www.sparkfun.com/qwiic">Qwiic Connect System</a>
        </div>
    </div>
</div>
</center>

One of the new, advanced features of our Processor Boards is that they take advantage of the [Qwiic connect system](https://www.sparkfun.com/qwiic). We recommend familiarizing yourself with the **Logic Levels** and **I<sup>2</sup>C** tutorials.  Click on the banner above to learn more about [Qwiic products](https://www.sparkfun.com/qwiic).

<center>
    <iframe width="600" height="327" src="https://www.youtube.com/embed/x0RDEHqFIF8" title="SparkFun's Qwiic Connect System" frameborder="0" allow="accelerometer; autoplay; clipboard-write; encrypted-media; gyroscope; picture-in-picture" allowfullscreen></iframe>
</center>

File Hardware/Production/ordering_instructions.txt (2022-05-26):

panel size, 116x142mm
PCB thickness, 1.6mm
number of layers, 4
soldermask color, Black
silkscreen color, White
oz copper, 1oz
finish, HASL lead free
stencils, top
pcs per panel, 4
min trace width, 0.1524mm / 0.0060in
min drill size, 0.3000mm / 0.0118in
filename to layer stackup 1/2/3/4: GTL, GL2, GL3, GBL

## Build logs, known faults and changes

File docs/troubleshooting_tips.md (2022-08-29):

!!! note
    <p><span class="glyphicon glyphicon-question-sign" aria-hidden="true"></span> <strong>Not working as expected and need help? </strong></p>
    <p><a href="https://www.sparkfun.com/sparkx">SparkX</a> products are rapidly produced to bring you the most cutting edge technology as it becomes available. These products are tested but come with no guarantees. Live technical support is not available for SparkX products. Head on over to our <a href="https://forum.sparkfun.com/viewforum.php?f=123">forum</a> for support or to ask a question.<p>
    <center>
    [SparkX Forum](https://forum.sparkfun.com/viewforum.php?f=123){ .md-button .md-button--primary }
    </center>
    <p>You'll need a <a href="https://forum.sparkfun.com/ucp.php?mode=register">Forum Account</a> to search the product forums and post questions.<p>

!!! attention
    u-blox provides products and services to "B2B Customers". Only business customers are eligible to register for a Thingstream (PointPerfect) account. You may be required to demonstrate that the use of the combo breakout is in relation to your trade, business, craft or profession. u-blox products and services are not intended for individual consumer use.

## PointPerfect L-band Reception

In order to receive the u-blox PointPerfect correction data, you will: need a suitable antenna; need to be located within contiguous USA or Europe; and have a clear view of the sky to the South.

### SparkFun GNSS Multi-Band L1/L2 Surveying Antenna - TOP106

We have been successful using the [SparkFun GNSS Multi-Band L1/L2 Surveying Antenna (TNC) - TOP106 (GPS-17751)](https://www.sparkfun.com/products/17751) antenna to receive
PointPerfect correction data in both the USA and Europe.

### PointPerfect Coverage

The PointPerfect GNSS augmentation service is available on a continental scale with seamless coverage in Europe and contiguous USA, including up to 12 nautical miles  (~ 22 km) off coastlines. u-blox are continuously expanding their coverage according to market demand.

<center>
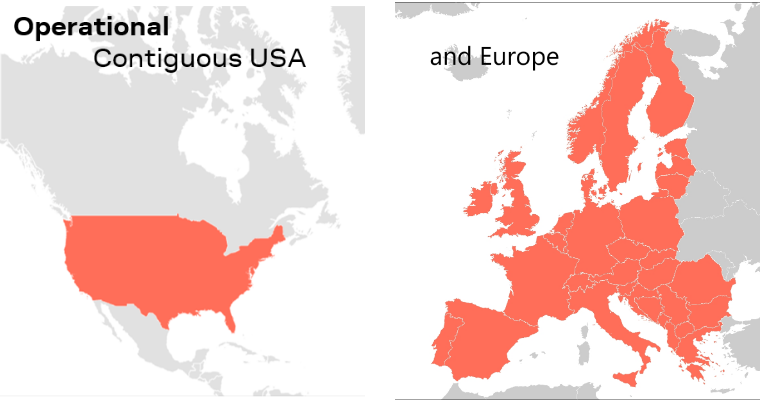
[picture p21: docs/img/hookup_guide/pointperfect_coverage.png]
PointPerfect Service Coverage
<br>
*PointPerfect Service Coverage. (Click to enlarge)*
</center>

### PointPerfect Satellite Broadcast

PointPerfect augmentation data is broadcast from satellites covering Europe and contiguous USA. The satellites are in geostationary orbits over the equator - the same as for satellite television broadcasts. It is essential that your antenna has an unobstructed view of the sky, especially to the South where the satellite is positioned.

Depending on your latitude, the satellite for your area could be low in the sky. You need to ensure that trees, buildings etc. are not blocking the signal.

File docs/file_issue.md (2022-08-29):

# Did we make a mistake?

Spot something wrong? Please let us know. 

!!! attention
    [SparkX](https://www.sparkfun.com/sparkx) products are rapidly produced to bring you the most cutting edge technology as it becomes available. These products are tested but come with no guarantees. Live technical support is not available for SparkX products. Head on over to our [forum](https://forum.sparkfun.com/viewforum.php?f=123) for support or to ask a question.

## Discrepancies in the Documentation

All of this documentation can be modified by you! Please help us make it better.

* These pages are contained in the [`docs` folder](https://github.com/sparkfunX/u-blox_ZED-F9P_NEO-D9S_Combo_Breakout/tree/main/docs) of the [SparkX u-blox ZED-F9P NEO-D9S Combo Breakout](https://github.com/sparkfunX/u-blox_ZED-F9P_NEO-D9S_Combo_Breakout) repository.

### Spot something wrong?
If a section of the documentation is incorrect, please [open an issue](https://github.com/sparkfunX/u-blox_ZED-F9P_NEO-D9S_Combo_Breakout/issues) and let us know.

### Do you have a suggested correction?
1. Fork this repo
2. Add your corrections or improvements to the markdown file
3. File a pull request with your changes, and enjoy making the ~~words~~ ~~worlds~~ world a better place.
    * Once received, the documentation specialist will automatically be notified.
    * We will review your suggested improvements to make sure they are correct and fit within our documentation standards.

## Problems in the Hardware Design

All of our designs are open-source! Please help us make it better.

* Our board design files are contained in the [`Hardware` folder](https://github.com/sparkfunX/u-blox_ZED-F9P_NEO-D9S_Combo_Breakout/tree/main/Hardware) of the [SparkX u-blox ZED-F9P NEO-D9S Combo Breakout](https://github.com/sparkfunX/u-blox_ZED-F9P_NEO-D9S_Combo_Breakout) repository. 

### Does something not make sense?
If part of the design is confusing, please [open an issue](https://github.com/sparkfunX/u-blox_ZED-F9P_NEO-D9S_Combo_Breakout/issues) and let us know.

### Did we forget to include an important function of the board?
* Please keep in mind that we may intentionally exclude certain functions of the board to meet our product design requirements. *(For example, our Qwiic Micro boards are intended to fit on a small board layout and only use I<sup>2</sup>C communincation; therefore, we may not have the SPI and interrupt pins available for users.)*
* If part of the board's functionality is missing, please [open an issue](https://github.com/sparkfunX/u-blox_ZED-F9P_NEO-D9S_Combo_Breakout/issues) and file a feature request.

### Do you wish to contribute directly to improving the board design?
1. Fork this repo
2. Add your design improvements
3. File a pull request with your changes, and enjoy making the ~~words~~ ~~worlds~~ world a better place.
    * Once received, the engineer in charge of the original design will automatically be notified.
    * We will review your suggested improvements, if they are within our board design standards and meet our product design requirements, we will flag these changes for our next board revision. *(Please note, that even if your suggestion is accepted, these changes may not be immediate. We may have to cycle through our current product inventory first.)*

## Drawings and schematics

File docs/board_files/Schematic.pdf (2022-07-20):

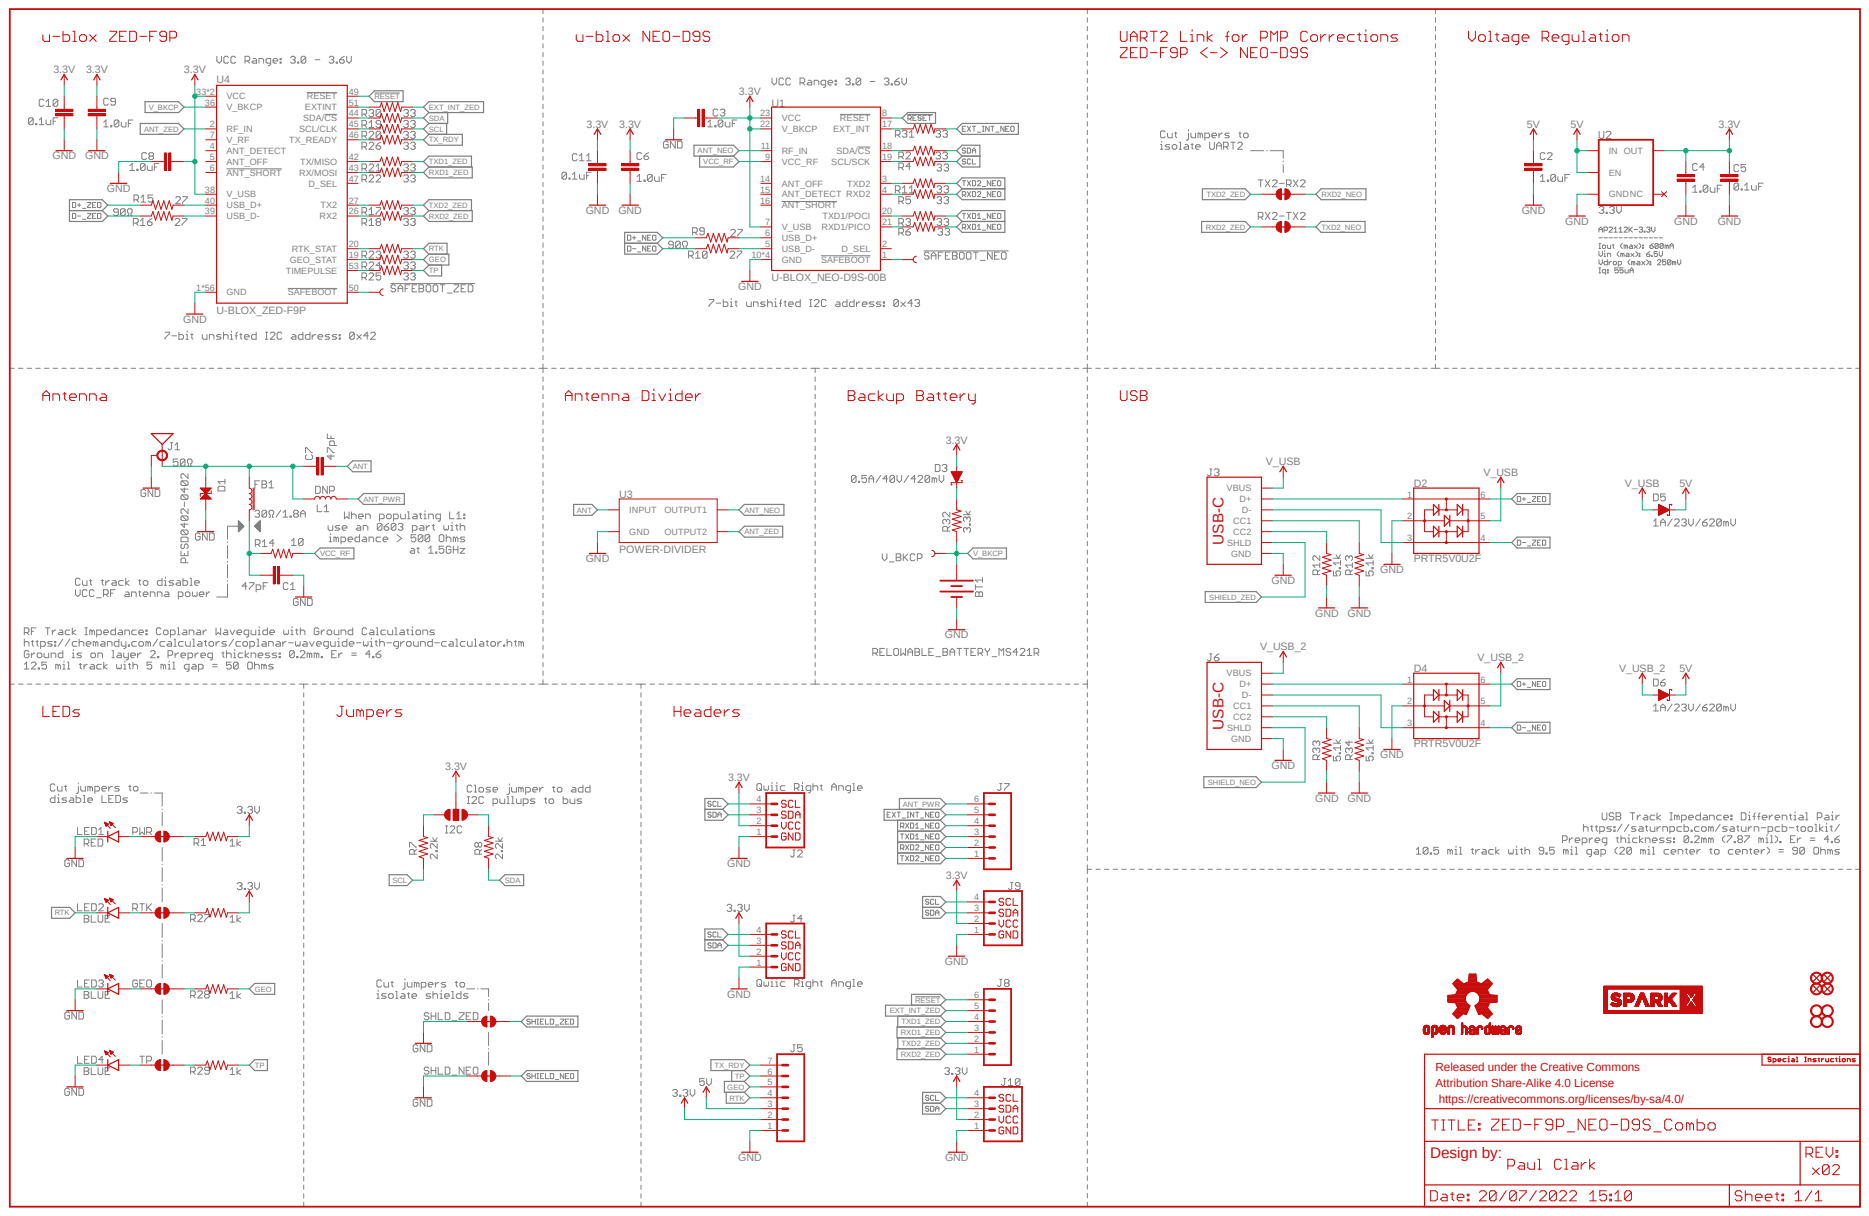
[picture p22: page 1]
GND; PRTR5V0U2F; U-BLOX_NEO-D9S-00B; POWER-DIVIDER; U-BLOX_ZED-F9P; V_USB; V_USB_2; V_USB_2 5V; INGNDOUT EN; 4 D2 GND VBUS CC1 D+D- CC2 SHLD; GND 10*4 VCC 23; RESET 8 EXT_INT 17 SDA/CS 18 SCL/SCK 19 TXD1/POCI 20 RXD1/PICO 21 ANT_OFF 14 V_BKCP 22 RF_IN 11 VCC_RF 9 V_USB 7 USB_D+ 6 USB_D- 5; D_SEL 2 SAFEBOOT 1 TXD2 3 RXD2 4 ANT_DETECT 15 ANT_SHORT 16U1; INPUT GND; OUTPUT1 OUTPUT2 U3 GND 1*56; VCC 33*2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

V_USB_2
VBUS CC1 D+D- CC2 SHLD
Design by: USB⁻C

Released under the Creative Commons
Attribution Share-Alike 4.0 License
https://creativecommons.org/licenses/by-sa/4.0/

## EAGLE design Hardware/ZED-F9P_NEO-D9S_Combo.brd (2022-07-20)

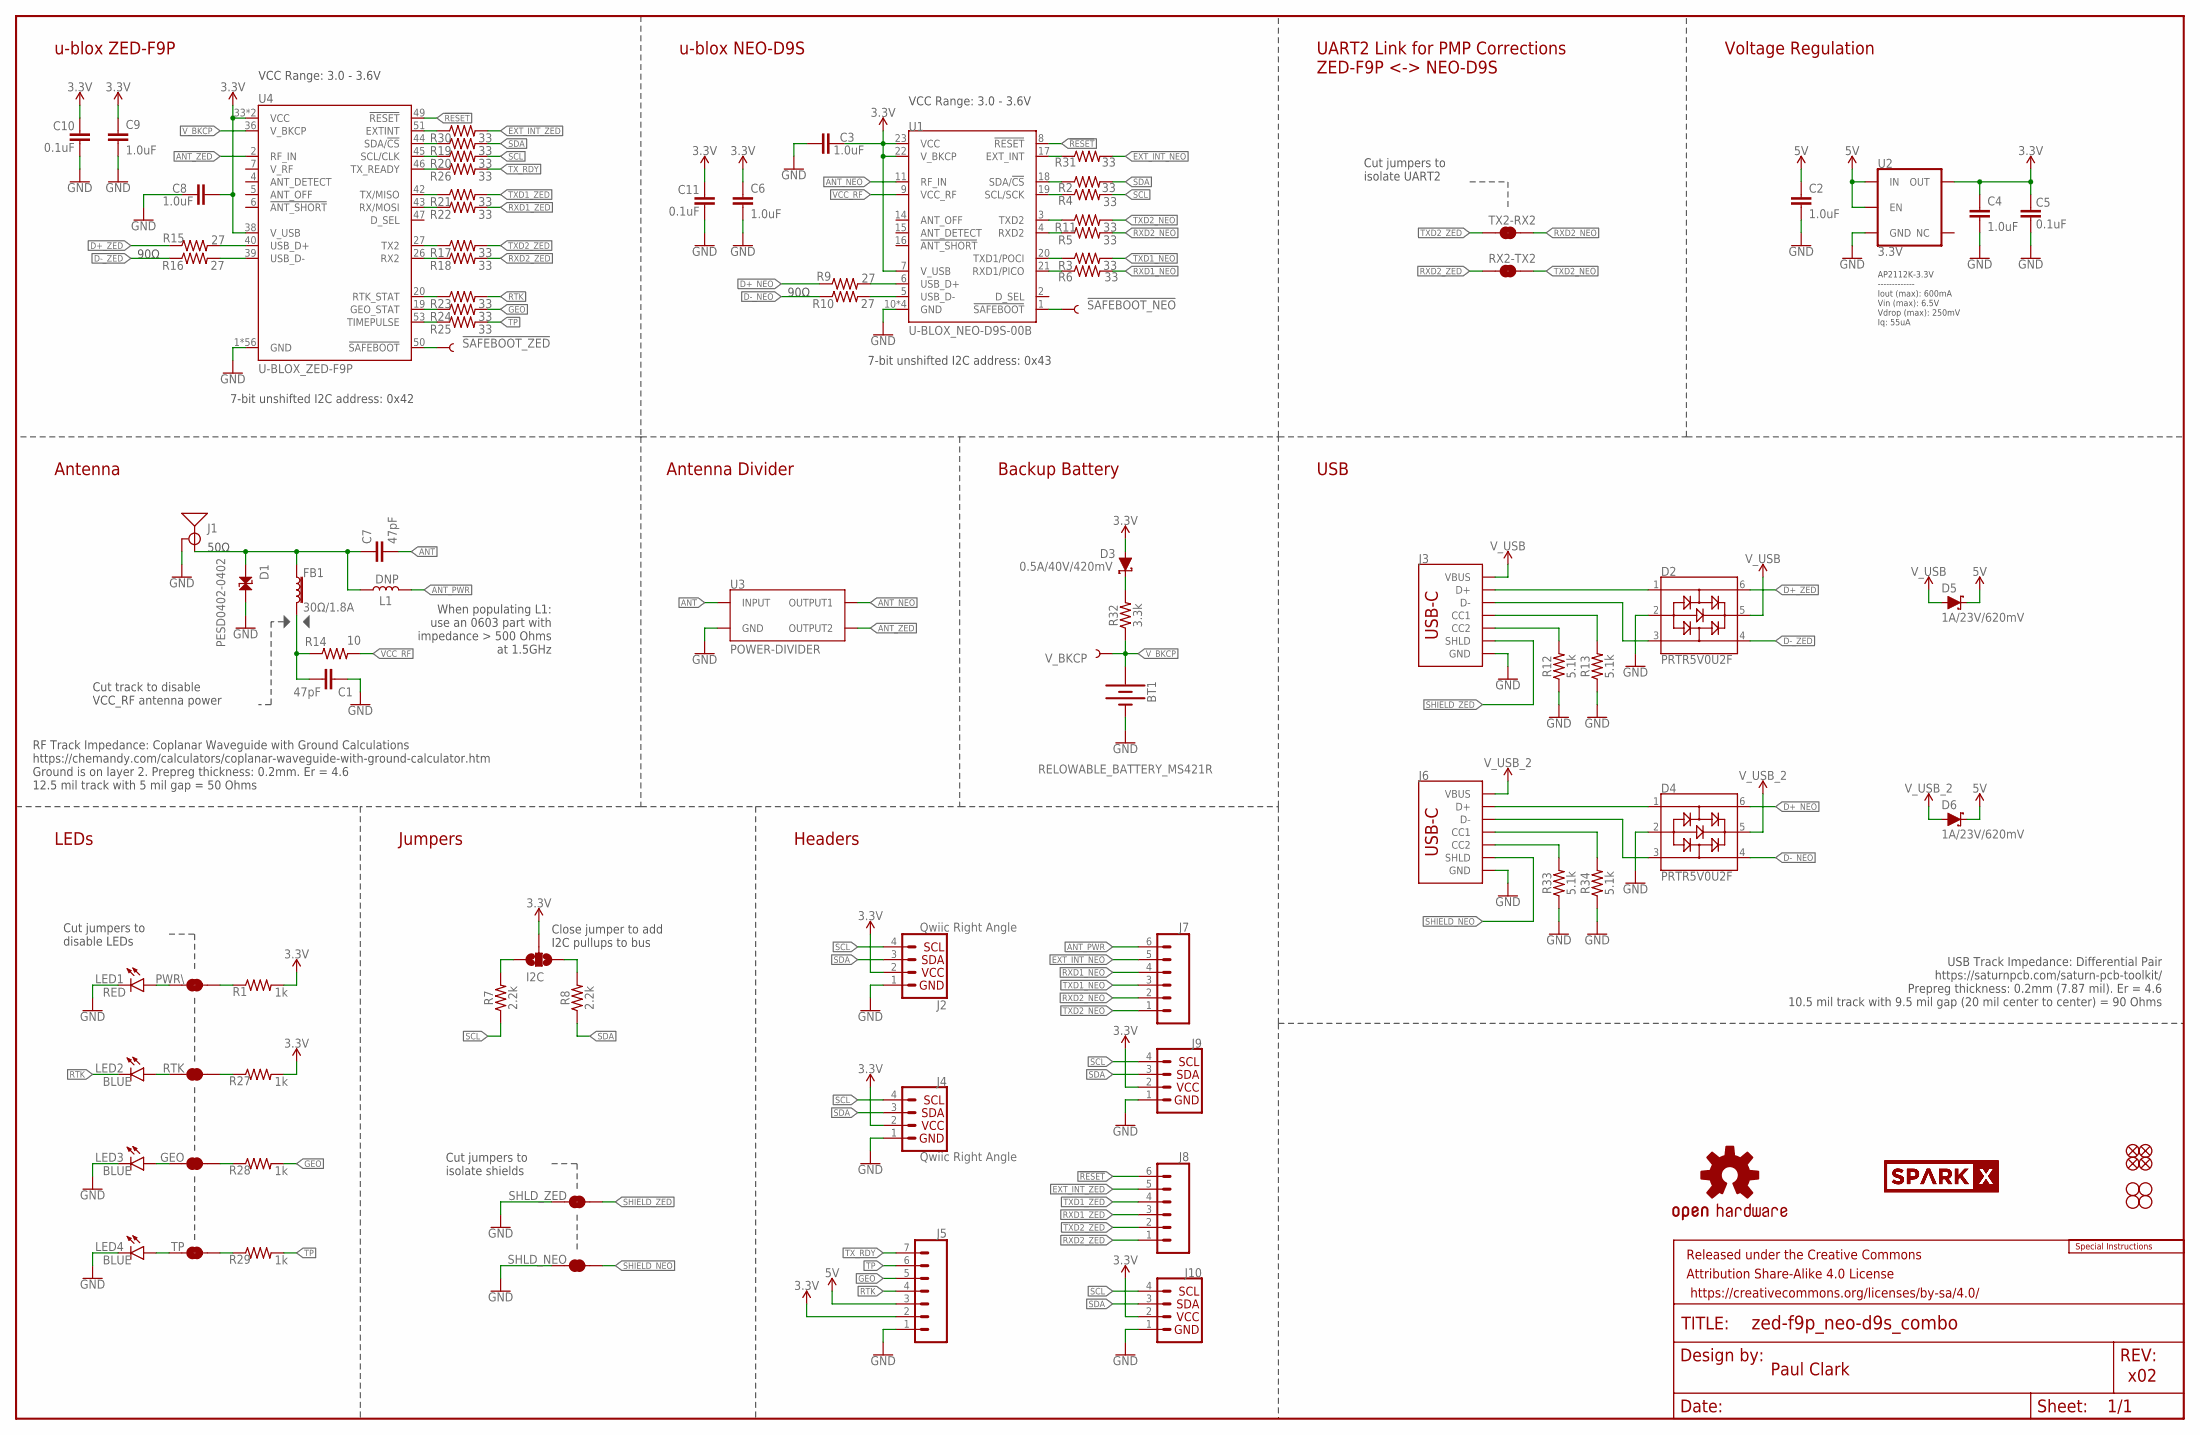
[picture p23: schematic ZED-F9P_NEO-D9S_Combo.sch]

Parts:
!SAFEBOOT_NEO!: TEST-POINTPOGO_PTH; 1X01_NO_SILK
!SAFEBOOT_ZED!: TEST-POINTPOGO_PTH; 1X01_NO_SILK
BT1: RELOWABLE_BATTERY_MS421R; MS421R_IV03E
C1, C7: 47pF; 0603
C2, C3, C4, C6, C8, C9: 1.0uF; 0603
C5, C10, C11: 0.1uF; 0603
D1: PESD0402-0402; 0402
D2, D4: PRTR5V0U2F; SOT886
D3: 0.5A/40V/420mV; SOD-323
D5, D6: 1A/23V/620mV; SOD-323
FB1: 30Ω/1.8A; 0603
FRAME2: FRAME-LEDGER; CREATIVE_COMMONS
GEO: JUMPER-SMT_2_NC_TRACE_SILK; SMT-JUMPER_2_NC_TRACE_SILK
I2C: JUMPER-SMT_3_NO_SILK; SMT-JUMPER_3_NO_SILK
J1: ANTENNA-SMA-GROUNDEDEDGE_SMA; SMA-EDGE
J2, J4: Qwiic Right Angle; JST04_1MM_RA
J3, J6: USB Female Type C Connector; USB-C-16P_4LAYER-PADS
J5: CONN_07NO_SILK; 1X07_NO_SILK
J7, J8: CONN_06NO_SILK_FEMALE_PTH; 1X06_NO_SILK
J9, J10: I2C_STANDARD_NO_SILK; 1X04_NO_SILK
JP21, JP61, JP71, JP81: FIDUCIALUFIDUCIAL; MICRO-FIDUCIAL
JP31, JP41, JP91, JP101: STAND-OFF
L1: DNP; 0603_NO-CREAM
LED1: RED; LED-0603
LED2, LED3, LED4: BLUE; LED-0603
LOGO4: OSHW-LOGOS; OSHW-LOGO-S
LOGO5: SPECIAL_INSTRUCTIONS-ORDERING; ORDERING_INSTRUCTIONS
PWR\: JUMPER-SMT_2_NC_TRACE_SILK; SMT-JUMPER_2_NC_TRACE_SILK
R1, R27, R28, R29: 1k; 0603
R2, R3, R4, R5, R6, R11, R17, R18, R19, R20, R21, R22, R23, R24, R25, R26, R30, R31: 33; 0603
R7, R8: 2.2k; 0603
R9, R10, R15, R16: 27; 0603
R12, R13, R33, R34: 5.1k; 0603
R14: 10; 0603
R32: 3.3k; 0603
RTK: JUMPER-SMT_2_NC_TRACE_SILK; SMT-JUMPER_2_NC_TRACE_SILK
RX2-TX2: JUMPER-SMT_2_NC_TRACE_SILK; SMT-JUMPER_2_NC_TRACE_SILK
SHLD_NEO: JUMPER-SMT_2_NC_TRACE_SILK; SMT-JUMPER_2_NC_TRACE_SILK
SHLD_ZED: JUMPER-SMT_2_NC_TRACE_SILK; SMT-JUMPER_2_NC_TRACE_SILK
TP: JUMPER-SMT_2_NC_TRACE_SILK; SMT-JUMPER_2_NC_TRACE_SILK
TX2-RX2: JUMPER-SMT_2_NC_TRACE_SILK; SMT-JUMPER_2_NC_TRACE_SILK
U1: U-BLOX_NEO-D9S-00B; NEO-M9N/M8T/M8U/D9S
U2: 3.3V; SOT23-5
U3: POWER-DIVIDER; PD0922J5050S2HF_ANA
U4: U-BLOX_ZED-F9P; ZED-F9P
U$77, U$78: SPARKX-LOGO4; SPARKX-MEDIUM
V_BKCP: TEST-POINT3X5; PAD.03X.05

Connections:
3.3V: C3.1, C4.1, C5.2, C6.1, C8.2, C9.1, C10.2, C11.2, D3.A, I2C.2, J2.2, J4.2, J5.2, J9.2, J10.2, R1.2, R27.2, U1.7 (V_USB), U1.22 (V_BKCP), U1.23 (VCC), U2.5 (OUT), U4.33 (VCC), U4.34 (VCC), U4.38 (V_USB)
5V: C2.1, D5.C, D6.C, J5.3, U2.1 (IN), U2.3 (EN)
!RESET!: J8.6, U1.8 (!RESET!), U4.49 (!RESET!)
!SAFEBOOT_NEO!: !SAFEBOOT_NEO!.1, U1.1 (!SAFEBOOT!)
!SAFEBOOT_ZED!: !SAFEBOOT_ZED!.1, U4.50 (!SAFEBOOT!)
ANT: C7.2, U3.2 (INPUT)
ANT_NEO: U1.11 (RF_IN), U3.4 (OUTPUT1)
ANT_PWR: J7.6, L1.2
ANT_VCC: C1.1, FB1.2, R14.1
ANT_ZED: U3.6 (OUTPUT2), U4.2 (RF_IN)
D+_NEO: D4.6, R9.1
D+_ZED: D2.6, R15.1
D-_NEO: D4.4, R10.1
D-_ZED: D2.4, R16.1
EXT_INT_NEO: J7.5, R31.2
EXT_INT_ZED: J8.5, R30.2
GEO: J5.5, R24.2, R28.2
GND: BT1.-, C1.2, C2.2, C3.2, C4.2, C5.1, C6.2, C8.1, C9.2, C10.1, C11.1, D1.2, D2.2, D4.2, J1.GND@0 (GND), J1.GND@1 (GND), J1.GND@2 (GND), J1.GND@3 (GND), J2.1, J3.GND, J3.GND2 (GND), J4.1, J5.1, J6.GND, J6.GND2 (GND), J9.1, J10.1, LED1.C, LED3.C, LED4.C, R12.1, R13.1, R33.1, R34.1, SHLD_NEO.1, SHLD_ZED.1, U1.10 (GND), U1.12 (GND), U1.13 (GND), U1.24 (GND), U2.2 (GND), U3.1 (GND), U3.3 (GND), U3.5 (GND), U4.1 (GND), U4.3 (GND), U4.12 (GND), U4.14 (GND), U4.32 (GND), U4.37 (GND), U4.41 (GND), U4.48 (GND), U4.55 (GND), U4.56 (GND), U4.57 (GND), U4.58 (GND), U4.59 (GND), U4.60 (GND), U4.61 (GND), U4.62 (GND), U4.63 (GND), U4.64 (GND), U4.65 (GND), U4.66 (GND), U4.67 (GND), U4.68 (GND), U4.69 (GND), U4.70 (GND), U4.71 (GND), U4.72 (GND), U4.73 (GND), U4.74 (GND), U4.75 (GND), U4.76 (GND), U4.77 (GND), U4.78 (GND), U4.79 (GND), U4.80 (GND), U4.81 (GND), U4.82 (GND), U4.83 (GND), U4.84 (GND), U4.85 (GND), U4.86 (GND), U4.87 (GND), U4.88 (GND), U4.89 (GND), U4.90 (GND), U4.91 (GND), U4.92 (GND), U4.93 (GND), U4.94 (GND), U4.95 (GND), U4.96 (GND), U4.97 (GND), U4.98 (GND), U4.99 (GND), U4.100 (GND), U4.101 (GND), U4.102 (GND)
unnamed: PWR\.2, R1.1
unnamed: R3.1, U1.20 (TXD1/POCI)
unnamed: R2.1, U1.18 (SDA/!CS!)
unnamed: R4.1, U1.19 (SCL/SCK)
unnamed: I2C.1, R8.2
unnamed: R6.1, U1.21 (RXD1/PICO)
unnamed: J3.B5 (CC2), R12.2
unnamed: I2C.3, R7.2
unnamed: J3.A5 (CC1), R13.2
unnamed: LED1.A, PWR\.1
unnamed: R9.2, U1.6 (USB_D+)
unnamed: R10.2, U1.5 (USB_D-)
unnamed: D3.C, R32.2
unnamed: R11.1, U1.3 (TXD2)
unnamed: R5.1, U1.4 (RXD2)
unnamed: R15.2, U4.40 (USB_D+)
unnamed: R16.2, U4.39 (USB_D-)
unnamed: R19.1, U4.44 (SDA/!CS!)
unnamed: R20.1, U4.45 (SCL/CLK)
unnamed: R21.1, U4.42 (TX/MISO)
unnamed: R22.1, U4.43 (RX/MOSI)
unnamed: R26.1, U4.46 (TX_READY)
unnamed: LED2.A, RTK.1
unnamed: R17.1, U4.27 (TX2)
unnamed: R18.1, U4.26 (RX2)
unnamed: GEO.1, LED3.A
unnamed: LED4.A, TP.1
unnamed: R27.1, RTK.2
unnamed: GEO.2, R28.1
unnamed: R29.1, TP.2
unnamed: R30.1, U4.51 (EXTINT)
unnamed: R31.1, U1.17 (EXT_INT)
unnamed: J6.B5 (CC2), R33.2
unnamed: J6.A5 (CC1), R34.2
unnamed: R23.1, U4.20 (RTK_STAT)
unnamed: R24.1, U4.19 (GEO_STAT)
unnamed: R25.1, U4.53 (TIMEPULSE)
RTK: J5.4, LED2.C, R23.2
RXD1_NEO: J7.4, R6.2
RXD1_ZED: J8.3, R22.2
RXD2_NEO: J7.2, R5.2, TX2-RX2.2
RXD2_ZED: J8.1, R18.2, RX2-TX2.1
SCL: J2.4, J4.4, J9.4, J10.4, R4.2, R7.1, R20.2
SDA: J2.3, J4.3, J9.3, J10.3, R2.2, R8.1, R19.2
SHIELD_NEO: J6.SHLD1 (SHLD), J6.SHLD2 (SHLD), J6.SHLD3 (SHLD), J6.SHLD4 (SHLD), SHLD_NEO.2
SHIELD_ZED: J3.SHLD1 (SHLD), J3.SHLD2 (SHLD), J3.SHLD3 (SHLD), J3.SHLD4 (SHLD), SHLD_ZED.2
SMA: C7.1, D1.1, FB1.1, J1.SIG (SIGNAL), L1.1
TP: J5.6, R25.2, R29.2
TXD1_NEO: J7.3, R3.2
TXD1_ZED: J8.4, R21.2
TXD2_NEO: J7.1, R11.2, RX2-TX2.2
TXD2_ZED: J8.2, R17.2, TX2-RX2.1
TX_RDY: J5.7, R26.2
USB_D+: D2.1, J3.A6 (D+), J3.B6 (D+)
USB_D+1: D4.1, J6.A6 (D+), J6.B6 (D+)
USB_D-: D2.3, J3.A7 (D-), J3.B7 (D-)
USB_D-1: D4.3, J6.A7 (D-), J6.B7 (D-)
VCC_RF: R14.2, U1.9 (VCC_RF)
V_BKCP: BT1.+, R32.1, U4.36 (V_BKCP), V_BKCP.1
V_USB: D2.5, D5.A, J3.VBUS1 (VBUS), J3.VBUS2 (VBUS)
V_USB_2: D4.5, D6.A, J6.VBUS1 (VBUS), J6.VBUS2 (VBUS)

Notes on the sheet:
x02
7-bit unshifted I2C address: 0x43
Close jumper to add I2C pullups to bus
Cut jumpers to disable LEDs
Paul Clark
Headers
LEDs
u-blox NEO-D9S
Antenna
USB
VCC Range: 3.0 - 3.6V
Cut jumpers to isolate shields
50Ω
Cut track to disable VCC_RF antenna power
90Ω
When populating L1: use an 0603 part with impedance > 500 Ohms at 1.5GHz
AP2112K-3.3V ------------- Iout (max): 600mA Vin (max): 6.5V Vdrop (max): 250mV Iq: 55uA
7-bit unshifted I2C address: 0x42
u-blox ZED-F9P
Antenna Divider
Jumpers
Backup Battery
Cut jumpers to isolate UART2
Voltage Regulation
RF Track Impedance: Coplanar Waveguide with Ground Calculations https://chemandy.com/calculators/coplanar-waveguide-with-ground-calculator.htm Ground is on layer 2. Prepreg thickness: 0.2mm. Er = 4.6 12.5 mil track with 5 mil gap = 50 Ohms
USB Track Impedance: Differential Pair https://saturnpcb.com/saturn-pcb-toolkit/ Prepreg thickness: 0.2mm (7.87 mil). Er = 4.6 10.5 mil track with 9.5 mil gap (20 mil center to center) = 90 Ohms
UART2 Link for PMP Corrections ZED-F9P <-> NEO-D9S

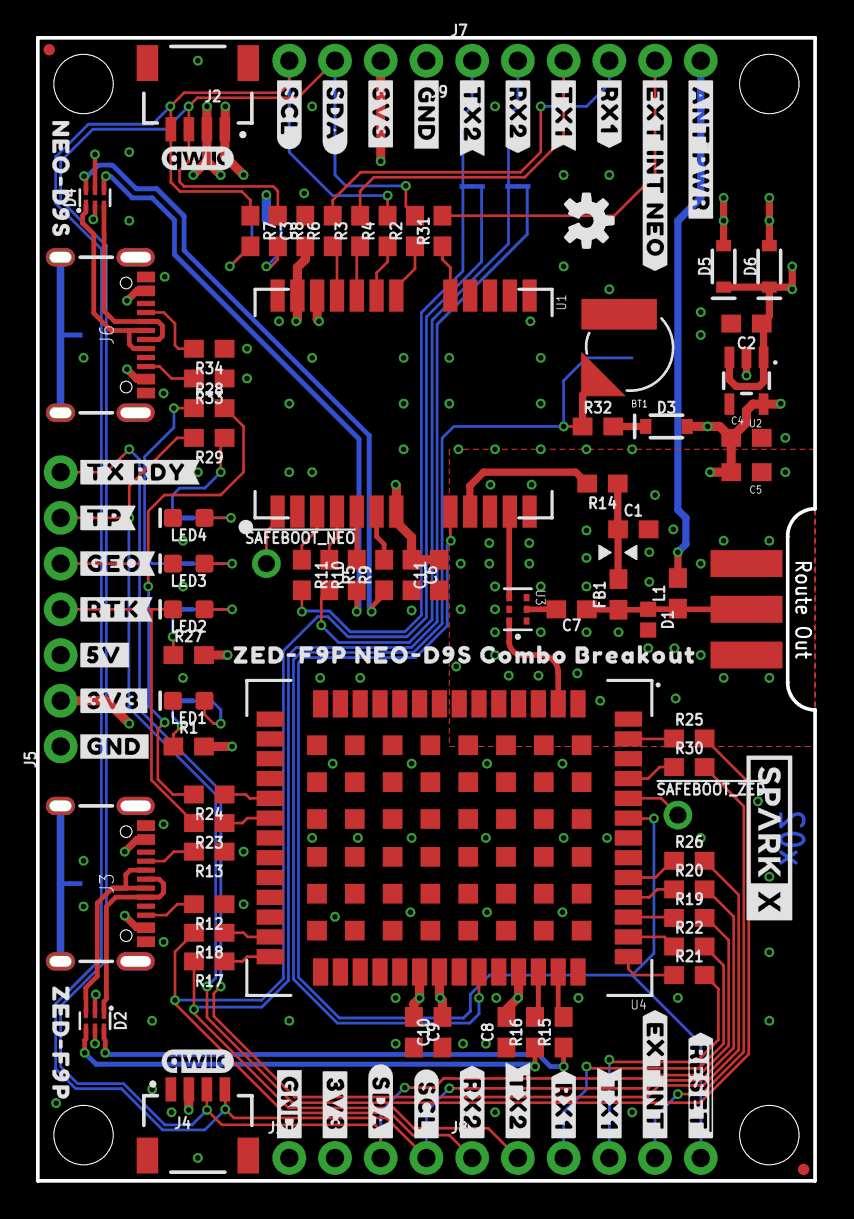
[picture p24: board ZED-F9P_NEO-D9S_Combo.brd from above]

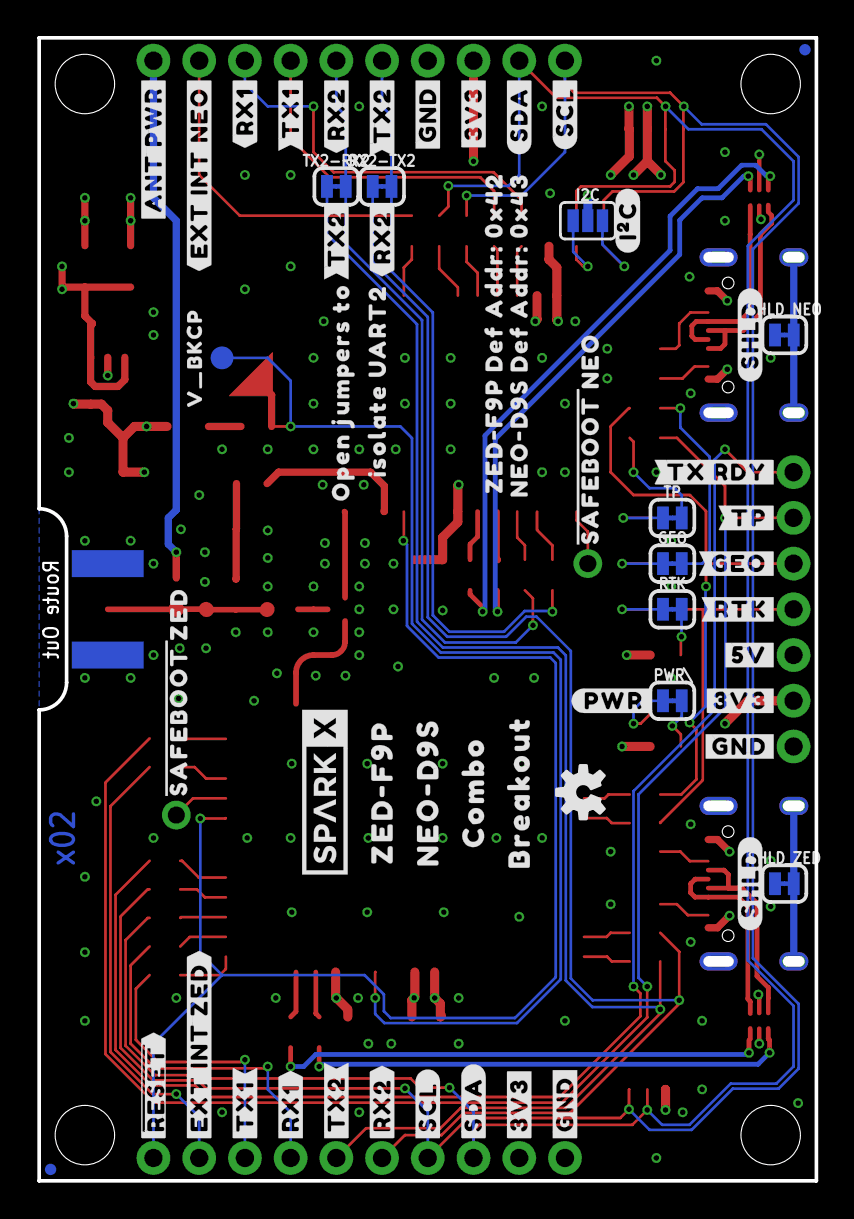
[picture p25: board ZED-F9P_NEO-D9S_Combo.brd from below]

Board: 4 copper layers, 43.2 x 63.5 mm, 174 parts (58 on the bottom side), 79 nets.

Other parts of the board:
LOGO1: OSHW-LOGOS; OSHW-LOGO-S
U$1, U$2, U$3: #GND#0
U$4, U$5, U$6: #GND#1
U$7, U$53: #SHLD#0
U$8, U$10: #SDA#0
U$9, U$13: #SCL#0
U$11, U$12: #SDA#1
U$14, U$38: QWIIC_4MM
U$15, U$30: #SCL#1
U$16: #RTK#0
U$17: #RTK#1
U$18: #GEO#0
U$19: #GEO#1
U$20: #5V#0
U$21: #5V#6
U$22, U$23, U$56: #3V3#0
U$24, U$25, U$70: #3V3#4
U$26: #TP#0
U$27: #TP#1
U$28: #TX_RDY#0
U$29: #TX_RDY#1
U$31, U$39, U$40: #TX2#0
U$32, U$34, U$35: #RX2#0
U$33: OPEN_JUMPERS_TO0
U$36, U$37: #RX2#3
U$41, U$42: #TX2#3
U$43, U$44: #RX1#0
U$45: ##RESET##0
U$46: ##RESET##1
U$47: #EXT_INT#0
U$48: #EXT_INT_ZED#0
U$49, U$50: #RX1#2
U$51, U$57: #TX1#0
U$52: #I�C#0
U$54: ISOLATE_UART21
U$55: NEO#D9S0
U$58: #ANT_PWR#0
U$59: #ANT_PWR#1
U$60, U$61: #TX1#2
U$62: #EXT_INT_NEO#0
U$63: #EXT_INT_NEO#1
U$64: ZED#F9P0
U$65: ZED#F9P10
U$66: NEO#D9S10
U$67: COMBO10
U$68: BREAKOUT11
U$69: #PWR#0
U$71: #SAFEBOOT#_NEO0
U$72: #SAFEBOOT#_ZED0
U$73: NEO#D9S_DEF_ADDR#_0X4310
U$74: ZED#F9P_DEF_ADDR#_0X420
U$75: ZED#F9P_NEO#D9S_COMBO_BREAKOUT0
U$76: V_BKCP0

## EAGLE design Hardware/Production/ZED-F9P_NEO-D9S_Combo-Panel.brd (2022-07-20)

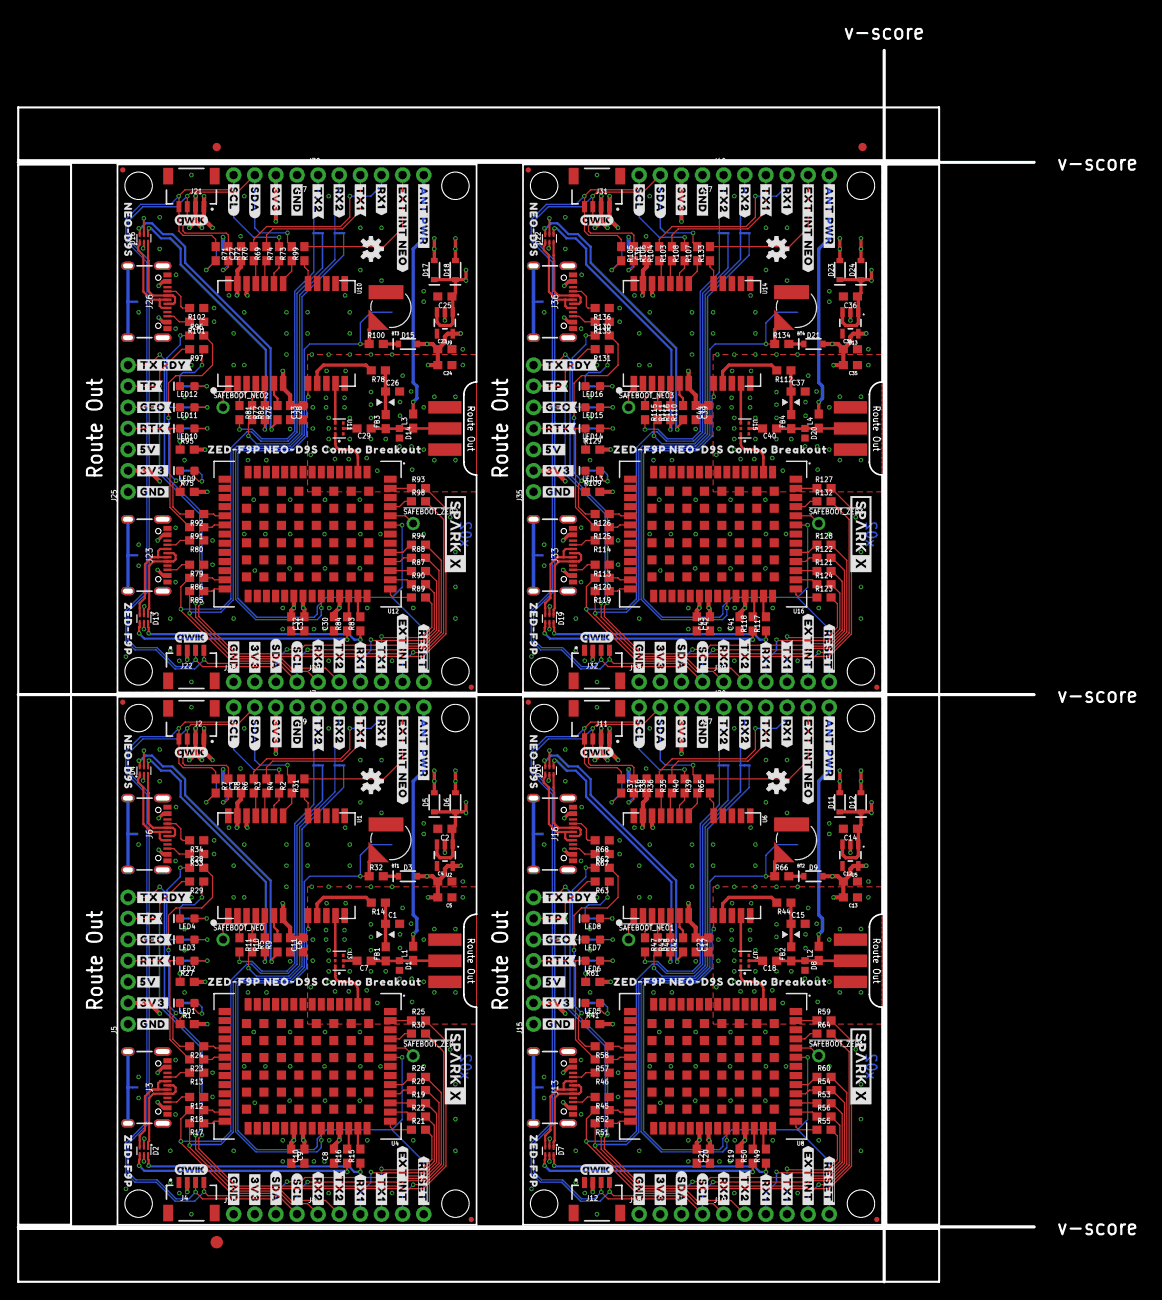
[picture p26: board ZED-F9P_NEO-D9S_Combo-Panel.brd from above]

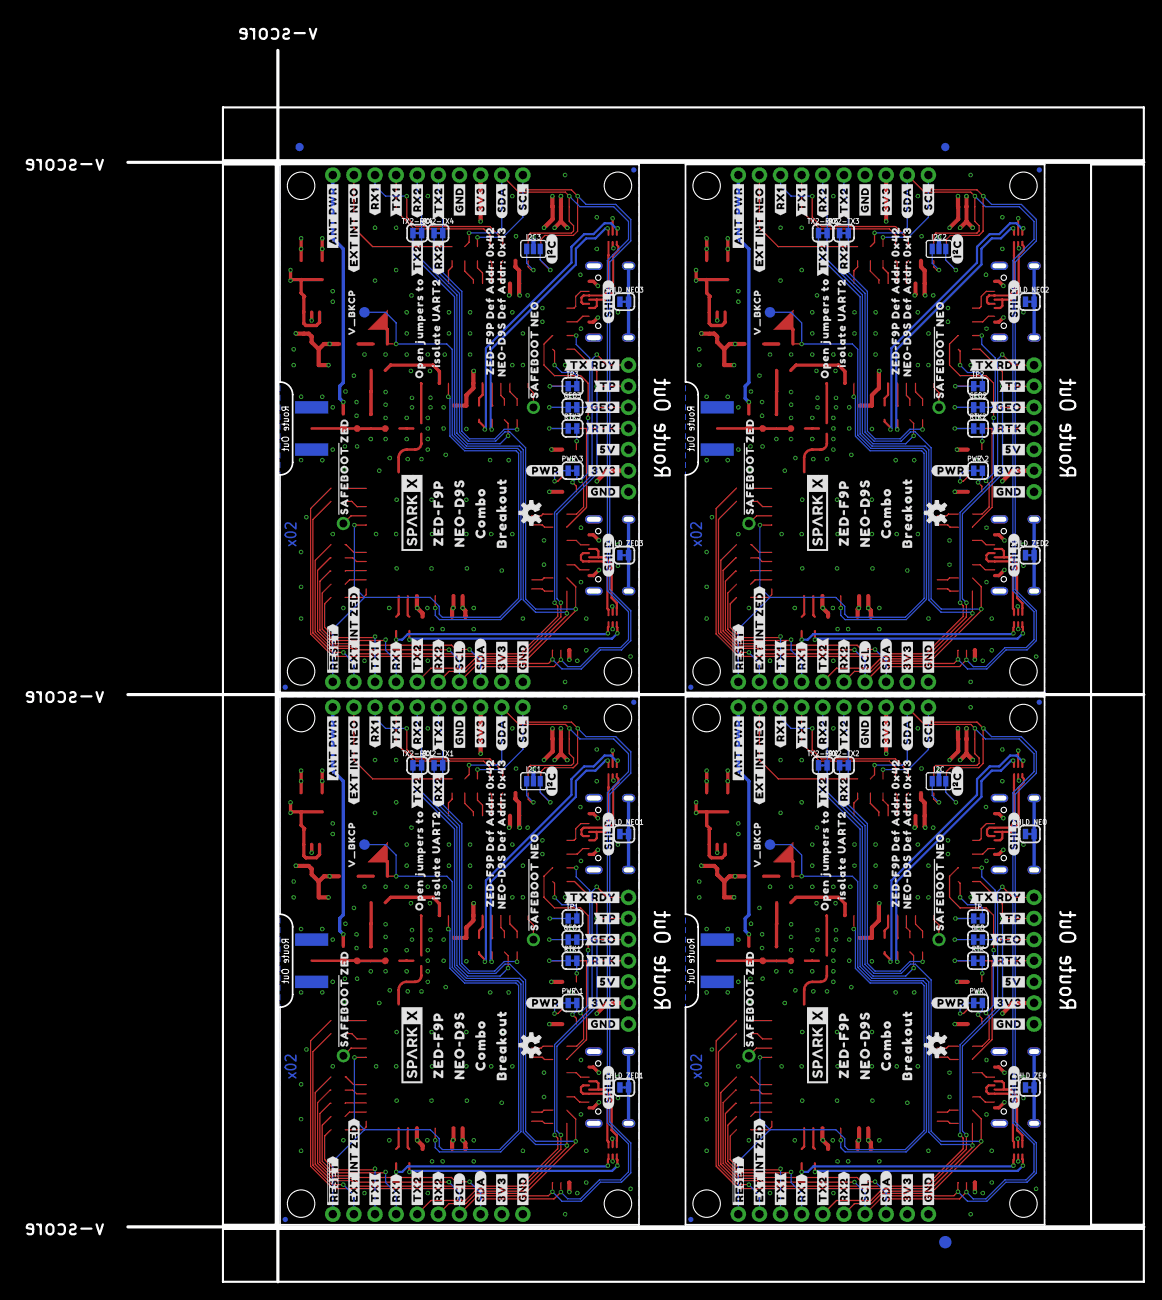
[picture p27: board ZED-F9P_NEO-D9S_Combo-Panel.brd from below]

Board: 4 copper layers, 122.2 x 148.1 mm, 694 parts (235 on the bottom side), 316 nets.

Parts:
!SAFEBOOT_NEO!, !SAFEBOOT_NEO!1, !SAFEBOOT_NEO!2, !SAFEBOOT_NEO!3: TEST-POINTPOGO_PTH; 1X01_NO_SILK
!SAFEBOOT_ZED!, !SAFEBOOT_ZED!1, !SAFEBOOT_ZED!2, !SAFEBOOT_ZED!3: TEST-POINTPOGO_PTH; 1X01_NO_SILK
BT1, BT2, BT3, BT4: RELOWABLE_BATTERY_MS421R; MS421R_IV03E
C1, C7, C15, C18, C26, C29, C37, C40: 47pF; 0603
C2, C3, C4, C6, C8, C9, C12, C14, C16, C17, C19, C20, C23, C25, C27, C28, C30, C31, C34, C36, C38, C39, C41, C42: 1.0uF; 0603
C5, C10, C11, C13, C21, C22, C24, C32, C33, C35, C43, C44: 0.1uF; 0603
D1, D8, D14, D20: PESD0402-0402; 0402
D2, D4, D7, D10, D13, D16, D19, D22: PRTR5V0U2F; SOT886
D3, D9, D15, D21: 0.5A/40V/420mV; SOD-323
D5, D6, D11, D12, D17, D18, D23, D24: 1A/23V/620mV; SOD-323
E$1, E$2, E$3, E$4: FIDUCIAL-1X2
E$5, E$6: FIDUCIAL-1.5X3
FB1, FB2, FB3, FB4: 30Ω/1.8A; 0603
GEO, GEO1, GEO2, GEO3: JUMPER-SMT_2_NC_TRACE_SILK; SMT-JUMPER_2_NC_TRACE_SILK
I2C, I2C1, I2C2, I2C3: JUMPER-SMT_3_NO_SILK; SMT-JUMPER_3_NO_SILK
J1, J14, J24, J34: ANTENNA-SMA-GROUNDEDEDGE_SMA; SMA-EDGE
J2, J4, J11, J12, J21, J22, J31, J32: Qwiic Right Angle; JST04_1MM_RA
J3, J6, J13, J16, J23, J26, J33, J36: USB Female Type C Connector; USB-C-16P_4LAYER-PADS
J5, J15, J25, J35: 1X07_NO_SILK
J7, J8, J19, J20, J29, J30, J39, J40: 1X06_NO_SILK
J9, J10, J17, J18, J27, J28, J37, J38: 1X04_NO_SILK
JP1, JP2, JP7, JP8, JP9, JP10, JP15, JP16, JP17, JP18, JP24, JP25, JP31, JP41, JP91, JP101: STAND-OFF
JP3, JP4, JP5, JP6, JP11, JP12, JP13, JP14, JP19, JP20, JP21, JP22, JP23, JP61, JP71, JP81: FIDUCIALUFIDUCIAL; MICRO-FIDUCIAL
L1, L2, L3, L4: DNP; 0603_NO-CREAM
LED1, LED5, LED9, LED13: RED; LED-0603
LED2, LED3, LED4, LED6, LED7, LED8, LED10, LED11, LED12, LED14, LED15, LED16: BLUE; LED-0603
LOGO1, LOGO2, LOGO3, LOGO4, LOGO5, LOGO6, LOGO7, LOGO8: OSHW-LOGOS; OSHW-LOGO-S
PWR\, PWR\1, PWR\2, PWR\3: JUMPER-SMT_2_NC_TRACE_SILK; SMT-JUMPER_2_NC_TRACE_SILK
R1, R27, R28, R29, R41, R61, R62, R63, R75, R95, R96, R97, R109, R129, R130, R131: 1k; 0603
R2, R3, R4, R5, R6, R11, R17, R18, R19, R20, R21, R22, R23, R24, R25, R26, R30, R31, R35, R36, R39, R40, R47, R48, R51, R52, R53, R54, R55, R56, R57, R58, R59, R60, R64, R65, R69, R70, R73, R74, R81, R82, R85, R86, R87, R88, R89, R90, R91, R92, R93, R94, R98, R99, R103, R104, R107, R108, R115, R116, R119, R120, R121, R122, R123, R124, R125, R126, R127, R128, R132, R133: 33; 0603
R7, R8, R37, R38, R71, R72, R105, R106: 2.2k; 0603
R9, R10, R15, R16, R42, R43, R49, R50, R76, R77, R83, R84, R110, R111, R117, R118: 27; 0603
R12, R13, R33, R34, R45, R46, R67, R68, R79, R80, R101, R102, R113, R114, R135, R136: 5.1k; 0603
R14, R44, R78, R112: 10; 0603
R32, R66, R100, R134: 3.3k; 0603
RTK, RTK1, RTK2, RTK3: JUMPER-SMT_2_NC_TRACE_SILK; SMT-JUMPER_2_NC_TRACE_SILK
RX2-TX1, RX2-TX2, RX2-TX3, RX2-TX4: JUMPER-SMT_2_NC_TRACE_SILK; SMT-JUMPER_2_NC_TRACE_SILK
SHLD_NEO, SHLD_NEO1, SHLD_NEO2, SHLD_NEO3: JUMPER-SMT_2_NC_TRACE_SILK; SMT-JUMPER_2_NC_TRACE_SILK
SHLD_ZED, SHLD_ZED1, SHLD_ZED2, SHLD_ZED3: JUMPER-SMT_2_NC_TRACE_SILK; SMT-JUMPER_2_NC_TRACE_SILK
TP, TP1, TP2, TP3: JUMPER-SMT_2_NC_TRACE_SILK; SMT-JUMPER_2_NC_TRACE_SILK
TX2-RX1, TX2-RX2, TX2-RX3, TX2-RX4: JUMPER-SMT_2_NC_TRACE_SILK; SMT-JUMPER_2_NC_TRACE_SILK
U1, U6, U10, U14: U-BLOX_NEO-D9S-00B; NEO-M9N/M8T/M8U/D9S
U2, U5, U9, U13: 3.3V; SOT23-5
U3, U7, U11, U15: POWER-DIVIDER; PD0922J5050S2HF_ANA
U4, U8, U12, U16: U-BLOX_ZED-F9P; ZED-F9P
U$1, U$2, U$3, U$80, U$81, U$82, U$158, U$159, U$160, U$236, U$237, U$238: #GND#0
U$4, U$5, U$6, U$83, U$84, U$85, U$161, U$162, U$163, U$239, U$240, U$241: #GND#1
U$7, U$53, U$96, U$127, U$174, U$205, U$252, U$283: #SHLD#0
U$8, U$10, U$128, U$129, U$206, U$207, U$284, U$285: #SDA#0
U$9, U$13, U$132, U$133, U$210, U$211, U$288, U$289: #SCL#0
U$11, U$12, U$130, U$131, U$208, U$209, U$286, U$287: #SDA#1
U$14, U$38, U$79, U$97, U$157, U$175, U$235, U$253: QWIIC_4MM
U$15, U$30, U$134, U$135, U$212, U$213, U$290, U$291: #SCL#1
U$16, U$101, U$179, U$257: #RTK#0
U$17, U$102, U$180, U$258: #RTK#1
U$18, U$103, U$181, U$259: #GEO#0
U$19, U$104, U$182, U$260: #GEO#1
U$20, U$86, U$164, U$242: #5V#0
U$21, U$87, U$165, U$243: #5V#6
U$22, U$23, U$56, U$88, U$89, U$98, U$166, U$167, U$176, U$244, U$245, U$254: #3V3#0
U$24, U$25, U$70, U$90, U$91, U$147, U$168, U$169, U$225, U$246, U$247, U$303: #3V3#4
U$26, U$105, U$183, U$261: #TP#0
U$27, U$106, U$184, U$262: #TP#1
U$28, U$107, U$185, U$263: #TX_RDY#0
U$29, U$108, U$186, U$264: #TX_RDY#1
U$31, U$39, U$40, U$113, U$114, U$136, U$191, U$192, U$214, U$269, U$270, U$292: #TX2#0
U$32, U$34, U$35, U$109, U$110, U$137, U$187, U$188, U$215, U$265, U$266, U$293: #RX2#0
U$33, U$144, U$222, U$300: OPEN_JUMPERS_TO0
U$36, U$37, U$111, U$112, U$189, U$190, U$267, U$268: #RX2#3
U$41, U$42, U$115, U$116, U$193, U$194, U$271, U$272: #TX2#3
U$43, U$44, U$117, U$118, U$195, U$196, U$273, U$274: #RX1#0
U$45, U$92, U$170, U$248: ##RESET##0
U$46, U$93, U$171, U$249: ##RESET##1
U$47, U$94, U$172, U$250: #EXT_INT#0
U$48, U$152, U$230, U$308: #EXT_INT_ZED#0
U$49, U$50, U$119, U$120, U$197, U$198, U$275, U$276: #RX1#2
U$51, U$57, U$121, U$122, U$199, U$200, U$277, U$278: #TX1#0
U$52, U$95, U$173, U$251: #I�C#0
U$54, U$145, U$223, U$301: ISOLATE_UART21
U$55, U$140, U$218, U$296: NEO#D9S0
U$58, U$99, U$177, U$255: #ANT_PWR#0
U$59, U$100, U$178, U$256: #ANT_PWR#1
U$60, U$61, U$123, U$124, U$201, U$202, U$279, U$280: #TX1#2
U$62, U$125, U$203, U$281: #EXT_INT_NEO#0
U$63, U$126, U$204, U$282: #EXT_INT_NEO#1
U$64, U$138, U$216, U$294: ZED#F9P0
U$65, U$139, U$217, U$295: ZED#F9P10
U$66, U$141, U$219, U$297: NEO#D9S10
U$67, U$142, U$220, U$298: COMBO10
U$68, U$143, U$221, U$299: BREAKOUT11
U$69, U$146, U$224, U$302: #PWR#0
U$71, U$148, U$226, U$304: #SAFEBOOT#_NEO0
U$72, U$149, U$227, U$305: #SAFEBOOT#_ZED0
U$73, U$150, U$228, U$306: NEO#D9S_DEF_ADDR#_0X4310
U$74, U$151, U$229, U$307: ZED#F9P_DEF_ADDR#_0X420
U$75, U$153, U$231, U$309: ZED#F9P_NEO#D9S_COMBO_BREAKOUT0
U$76, U$154, U$232, U$310: V_BKCP0
U$77, U$78, U$155, U$156, U$233, U$234, U$311, U$312: SPARKX-LOGO4; SPARKX-MEDIUM
V_BKCP, V_BKCP1, V_BKCP2, V_BKCP3: TEST-POINT3X5; PAD.03X.05

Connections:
3.3V: C3.1, C4.1, C5.2, C6.1, C8.2, C9.1, C10.2, C11.2, D3.A, I2C.2, J2.2, J4.2, J5.2, J9.2, J10.2, R1.2, R27.2, U1.7, U1.22, U1.23, U2.5, U4.33, U4.34, U4.38
3.3V1: C12.1, C13.2, C16.1, C17.1, C19.2, C20.1, C21.2, C22.2, D9.A, I2C1.2, J11.2, J12.2, J15.2, J17.2, J18.2, R41.2, R61.2, U5.5, U6.7, U6.22, U6.23, U8.33, U8.34, U8.38
3.3V2: C23.1, C24.2, C27.1, C28.1, C30.2, C31.1, C32.2, C33.2, D15.A, I2C2.2, J21.2, J22.2, J25.2, J27.2, J28.2, R75.2, R95.2, U9.5, U10.7, U10.22, U10.23, U12.33, U12.34, U12.38
3.3V3: C34.1, C35.2, C38.1, C39.1, C41.2, C42.1, C43.2, C44.2, D21.A, I2C3.2, J31.2, J32.2, J35.2, J37.2, J38.2, R109.2, R129.2, U13.5, U14.7, U14.22, U14.23, U16.33, U16.34, U16.38
5V: C2.1, D5.C, D6.C, J5.3, U2.1, U2.3
5V1: C14.1, D11.C, D12.C, J15.3, U5.1, U5.3
5V2: C25.1, D17.C, D18.C, J25.3, U9.1, U9.3
5V3: C36.1, D23.C, D24.C, J35.3, U13.1, U13.3
!RESET!: J8.6, U1.8, U4.49
!RESET!1: J19.6, U6.8, U8.49
!RESET!2: J29.6, U10.8, U12.49
!RESET!3: J39.6, U14.8, U16.49
!SAFEBOOT_NEO!: !SAFEBOOT_NEO!.1, U1.1
!SAFEBOOT_NEO!1: !SAFEBOOT_NEO!1.1, U6.1
!SAFEBOOT_NEO!2: !SAFEBOOT_NEO!2.1, U10.1
!SAFEBOOT_NEO!3: !SAFEBOOT_NEO!3.1, U14.1
!SAFEBOOT_ZED!: !SAFEBOOT_ZED!.1, U4.50
!SAFEBOOT_ZED!1: !SAFEBOOT_ZED!1.1, U8.50
!SAFEBOOT_ZED!2: !SAFEBOOT_ZED!2.1, U12.50
!SAFEBOOT_ZED!3: !SAFEBOOT_ZED!3.1, U16.50
ANT: C7.2, U3.2
ANT1: C18.2, U7.2
ANT2: C29.2, U11.2
ANT3: C40.2, U15.2
ANT_NEO: U1.11, U3.4
ANT_NEO1: U6.11, U7.4
ANT_NEO2: U10.11, U11.4
ANT_NEO3: U14.11, U15.4
ANT_PWR: J7.6, L1.2
ANT_PWR1: J20.6, L2.2
ANT_PWR2: J30.6, L3.2
ANT_PWR3: J40.6, L4.2
ANT_VCC: C1.1, FB1.2, R14.1
ANT_VCC1: C15.1, FB2.2, R44.1
ANT_VCC2: C26.1, FB3.2, R78.1
ANT_VCC3: C37.1, FB4.2, R112.1
ANT_ZED: U3.6, U4.2
ANT_ZED1: U7.6, U8.2
ANT_ZED2: U11.6, U12.2
ANT_ZED3: U15.6, U16.2
D+_NEO: D4.6, R9.1
D+_NEO1: D10.6, R42.1
D+_NEO2: D16.6, R76.1
D+_NEO3: D22.6, R110.1
D+_ZED: D2.6, R15.1
D+_ZED1: D7.6, R49.1
D+_ZED2: D13.6, R83.1
D+_ZED3: D19.6, R117.1
D-_NEO: D4.4, R10.1
D-_NEO1: D10.4, R43.1
D-_NEO2: D16.4, R77.1
D-_NEO3: D22.4, R111.1
D-_ZED: D2.4, R16.1
D-_ZED1: D7.4, R50.1
D-_ZED2: D13.4, R84.1
D-_ZED3: D19.4, R118.1
EXT_INT_NEO: J7.5, R31.2
EXT_INT_NEO1: J20.5, R65.2
EXT_INT_NEO2: J30.5, R99.2
EXT_INT_NEO3: J40.5, R133.2
EXT_INT_ZED: J8.5, R30.2
EXT_INT_ZED1: J19.5, R64.2
EXT_INT_ZED2: J29.5, R98.2
EXT_INT_ZED3: J39.5, R132.2
GEO: J5.5, R24.2, R28.2
GEO1: J15.5, R58.2, R62.2
GEO2: J25.5, R92.2, R96.2
GEO3: J35.5, R126.2, R130.2
GND: BT1.-, C1.2, C2.2, C3.2, C4.2, C5.1, C6.2, C8.1, C9.2, C10.1, C11.1, D1.2, D2.2, D4.2, J1.GND@0, J1.GND@1, J1.GND@2, J1.GND@3, J2.1, J3.GND, J3.GND2, J4.1, J5.1, J6.GND, J6.GND2, J9.1, J10.1, LED1.C, LED3.C, LED4.C, R12.1, R13.1, R33.1, R34.1, SHLD_NEO.1, SHLD_ZED.1, U1.10, U1.12, U1.13, U1.24, U2.2, U3.1, U3.3, U3.5, U4.1, U4.3, U4.12, U4.14, U4.32, U4.37, U4.41, U4.48, U4.55, U4.56, U4.57, U4.58, U4.59, U4.60, U4.61, U4.62, U4.63, U4.64, U4.65, U4.66, U4.67, U4.68, U4.69, U4.70, U4.71, U4.72, U4.73, U4.74, U4.75, U4.76, U4.77, U4.78, U4.79, U4.80, U4.81, U4.82, U4.83, U4.84, U4.85, U4.86, U4.87, U4.88, U4.89, U4.90, U4.91, U4.92, U4.93, U4.94, U4.95, U4.96, U4.97, U4.98, U4.99, U4.100, U4.101, U4.102
GND1: BT2.-, C12.2, C13.1, C14.2, C15.2, C16.2, C17.2, C19.1, C20.2, C21.1, C22.1, D7.2, D8.2, D10.2, J11.1, J12.1, J13.GND, J13.GND2, J14.GND@0, J14.GND@1, J14.GND@2, J14.GND@3, J15.1, J16.GND, J16.GND2, J17.1, J18.1, LED5.C, LED7.C, LED8.C, R45.1, R46.1, R67.1, R68.1, SHLD_NEO1.1, SHLD_ZED1.1, U5.2, U6.10, U6.12, U6.13, U6.24, U7.1, U7.3, U7.5, U8.1, U8.3, U8.12, U8.14, U8.32, U8.37, U8.41, U8.48, U8.55, U8.56, U8.57, U8.58, U8.59, U8.60, U8.61, U8.62, U8.63, U8.64, U8.65, U8.66, U8.67, U8.68, U8.69, U8.70, U8.71, U8.72, U8.73, U8.74, U8.75, U8.76, U8.77, U8.78, U8.79, U8.80, U8.81, U8.82, U8.83, U8.84, U8.85, U8.86, U8.87, U8.88, U8.89, U8.90, U8.91, U8.92, U8.93, U8.94, U8.95, U8.96, U8.97, U8.98, U8.99, U8.100, U8.101, U8.102
GND2: BT3.-, C23.2, C24.1, C25.2, C26.2, C27.2, C28.2, C30.1, C31.2, C32.1, C33.1, D13.2, D14.2, D16.2, J21.1, J22.1, J23.GND, J23.GND2, J24.GND@0, J24.GND@1, J24.GND@2, J24.GND@3, J25.1, J26.GND, J26.GND2, J27.1, J28.1, LED9.C, LED11.C, LED12.C, R79.1, R80.1, R101.1, R102.1, SHLD_NEO2.1, SHLD_ZED2.1, U9.2, U10.10, U10.12, U10.13, U10.24, U11.1, U11.3, U11.5, U12.1, U12.3, U12.12, U12.14, U12.32, U12.37, U12.41, U12.48, U12.55, U12.56, U12.57, U12.58, U12.59, U12.60, U12.61, U12.62, U12.63, U12.64, U12.65, U12.66, U12.67, U12.68, U12.69, U12.70, U12.71, U12.72, U12.73, U12.74, U12.75, U12.76, U12.77, U12.78, U12.79, U12.80, U12.81, U12.82, U12.83, U12.84, U12.85, U12.86, U12.87, U12.88, U12.89, U12.90, U12.91, U12.92, U12.93, U12.94, U12.95, U12.96, U12.97, U12.98, U12.99, U12.100, U12.101, U12.102
GND3: BT4.-, C34.2, C35.1, C36.2, C37.2, C38.2, C39.2, C41.1, C42.2, C43.1, C44.1, D19.2, D20.2, D22.2, J31.1, J32.1, J33.GND, J33.GND2, J34.GND@0, J34.GND@1, J34.GND@2, J34.GND@3, J35.1, J36.GND, J36.GND2, J37.1, J38.1, LED13.C, LED15.C, LED16.C, R113.1, R114.1, R135.1, R136.1, SHLD_NEO3.1, SHLD_ZED3.1, U13.2, U14.10, U14.12, U14.13, U14.24, U15.1, U15.3, U15.5, U16.1, U16.3, U16.12, U16.14, U16.32, U16.37, U16.41, U16.48, U16.55, U16.56, U16.57, U16.58, U16.59, U16.60, U16.61, U16.62, U16.63, U16.64, U16.65, U16.66, U16.67, U16.68, U16.69, U16.70, U16.71, U16.72, U16.73, U16.74, U16.75, U16.76, U16.77, U16.78, U16.79, U16.80, U16.81, U16.82, U16.83, U16.84, U16.85, U16.86, U16.87, U16.88, U16.89, U16.90, U16.91, U16.92, U16.93, U16.94, U16.95, U16.96, U16.97, U16.98, U16.99, U16.100, U16.101, U16.102
unnamed: PWR\.2, R1.1
unnamed: R3.1, U1.20
unnamed: R2.1, U1.18
unnamed: R4.1, U1.19
unnamed: I2C.1, R8.2
unnamed: R6.1, U1.21
unnamed: J3.B5, R12.2
unnamed: I2C.3, R7.2
unnamed: J3.A5, R13.2
unnamed: LED1.A, PWR\.1
unnamed: R9.2, U1.6
unnamed: R10.2, U1.5
unnamed: D3.C, R32.2
unnamed: R11.1, U1.3
unnamed: R5.1, U1.4
unnamed: R15.2, U4.40
unnamed: R16.2, U4.39
unnamed: R19.1, U4.44
unnamed: R20.1, U4.45
unnamed: R21.1, U4.42
unnamed: R22.1, U4.43
unnamed: R26.1, U4.46
unnamed: LED2.A, RTK.1
unnamed: R17.1, U4.27
unnamed: R18.1, U4.26
unnamed: GEO.1, LED3.A
unnamed: LED4.A, TP.1
unnamed: R27.1, RTK.2
unnamed: GEO.2, R28.1
unnamed: R29.1, TP.2
unnamed: R30.1, U4.51
unnamed: R31.1, U1.17
unnamed: J6.B5, R33.2
unnamed: J6.A5, R34.2
unnamed: R23.1, U4.20
unnamed: R24.1, U4.19
unnamed: R25.1, U4.53
unnamed: I2C1.1, R38.2
unnamed: I2C1.3, R37.2
unnamed: R42.2, U6.6
unnamed: R43.2, U6.5
unnamed: J13.B5, R45.2
unnamed: J13.A5, R46.2
unnamed: R47.1, U6.3
unnamed: R48.1, U6.4
unnamed: R35.1, U6.20
unnamed: R36.1, U6.21
unnamed: R39.1, U6.18
unnamed: R40.1, U6.19
unnamed: R49.2, U8.40
unnamed: R50.2, U8.39
unnamed: R53.1, U8.44
unnamed: R54.1, U8.45
unnamed: R55.1, U8.42
unnamed: R56.1, U8.43
unnamed: R51.1, U8.27
unnamed: R52.1, U8.26
unnamed: R60.1, U8.46
unnamed: LED6.A, RTK1.1
unnamed: GEO1.1, LED7.A
unnamed: LED8.A, TP1.1
unnamed: R61.1, RTK1.2
unnamed: GEO1.2, R62.1
unnamed: R63.1, TP1.2
unnamed: R57.1, U8.20
unnamed: R58.1, U8.19
unnamed: R59.1, U8.53
unnamed: R64.1, U8.51
unnamed: R65.1, U6.17
unnamed: D9.C, R66.2
unnamed: J16.B5, R67.2
unnamed: J16.A5, R68.2
unnamed: PWR\1.2, R41.1
unnamed: LED5.A, PWR\1.1
unnamed: I2C2.1, R72.2
unnamed: I2C2.3, R71.2
unnamed: R76.2, U10.6
unnamed: R77.2, U10.5
unnamed: J23.B5, R79.2
unnamed: J23.A5, R80.2
unnamed: R81.1, U10.3
unnamed: R82.1, U10.4
unnamed: R69.1, U10.20
unnamed: R70.1, U10.21
unnamed: R73.1, U10.18
unnamed: R74.1, U10.19
unnamed: R83.2, U12.40
unnamed: R84.2, U12.39
unnamed: R87.1, U12.44
unnamed: R88.1, U12.45
unnamed: R89.1, U12.42
unnamed: R90.1, U12.43
unnamed: R85.1, U12.27
unnamed: R86.1, U12.26
unnamed: R94.1, U12.46
unnamed: LED10.A, RTK2.1
unnamed: GEO2.1, LED11.A
unnamed: LED12.A, TP2.1
unnamed: R95.1, RTK2.2
unnamed: GEO2.2, R96.1
unnamed: R97.1, TP2.2
unnamed: R91.1, U12.20
unnamed: R92.1, U12.19
unnamed: R93.1, U12.53
unnamed: R98.1, U12.51
unnamed: R99.1, U10.17
unnamed: D15.C, R100.2
unnamed: J26.B5, R101.2
unnamed: J26.A5, R102.2
unnamed: PWR\2.2, R75.1
unnamed: LED9.A, PWR\2.1
unnamed: I2C3.1, R106.2
unnamed: I2C3.3, R105.2
unnamed: R110.2, U14.6
unnamed: R111.2, U14.5
unnamed: J33.B5, R113.2
unnamed: J33.A5, R114.2
unnamed: R115.1, U14.3
unnamed: R116.1, U14.4
unnamed: R103.1, U14.20
unnamed: R104.1, U14.21
unnamed: R107.1, U14.18
unnamed: R108.1, U14.19
unnamed: R117.2, U16.40
unnamed: R118.2, U16.39
unnamed: R121.1, U16.44
unnamed: R122.1, U16.45
unnamed: R123.1, U16.42
unnamed: R124.1, U16.43
unnamed: R119.1, U16.27
unnamed: R120.1, U16.26
unnamed: R128.1, U16.46
unnamed: LED14.A, RTK3.1
unnamed: GEO3.1, LED15.A
unnamed: LED16.A, TP3.1
unnamed: R129.1, RTK3.2
unnamed: GEO3.2, R130.1
unnamed: R131.1, TP3.2
unnamed: R125.1, U16.20
unnamed: R126.1, U16.19
unnamed: R127.1, U16.53
unnamed: R132.1, U16.51
unnamed: R133.1, U14.17
unnamed: D21.C, R134.2
unnamed: J36.B5, R135.2
unnamed: J36.A5, R136.2
unnamed: PWR\3.2, R109.1
unnamed: LED13.A, PWR\3.1
RTK: J5.4, LED2.C, R23.2
RTK1: J15.4, LED6.C, R57.2
RTK2: J25.4, LED10.C, R91.2
RTK3: J35.4, LED14.C, R125.2
RXD1_NEO: J7.4, R6.2
RXD1_NEO1: J20.4, R36.2
RXD1_NEO2: J30.4, R70.2
RXD1_NEO3: J40.4, R104.2
RXD1_ZED: J8.3, R22.2
RXD1_ZED1: J19.3, R56.2
RXD1_ZED2: J29.3, R90.2
RXD1_ZED3: J39.3, R124.2
RXD2_NEO: J7.2, R5.2, TX2-RX2.2
RXD2_NEO1: J20.2, R48.2, TX2-RX1.2
RXD2_NEO2: J30.2, R82.2, TX2-RX3.2
RXD2_NEO3: J40.2, R116.2, TX2-RX4.2
RXD2_ZED: J8.1, R18.2, RX2-TX2.1
RXD2_ZED1: J19.1, R52.2, RX2-TX1.1
RXD2_ZED2: J29.1, R86.2, RX2-TX3.1
RXD2_ZED3: J39.1, R120.2, RX2-TX4.1
SCL: J2.4, J4.4, J9.4, J10.4, R4.2, R7.1, R20.2
SCL1: J11.4, J12.4, J17.4, J18.4, R37.1, R40.2, R54.2
SCL2: J21.4, J22.4, J27.4, J28.4, R71.1, R74.2, R88.2
SCL3: J31.4, J32.4, J37.4, J38.4, R105.1, R108.2, R122.2
SDA: J2.3, J4.3, J9.3, J10.3, R2.2, R8.1, R19.2
SDA1: J11.3, J12.3, J17.3, J18.3, R38.1, R39.2, R53.2
SDA2: J21.3, J22.3, J27.3, J28.3, R72.1, R73.2, R87.2
SDA3: J31.3, J32.3, J37.3, J38.3, R106.1, R107.2, R121.2
SHIELD_NEO: J6.SHLD1, J6.SHLD2, J6.SHLD3, J6.SHLD4, SHLD_NEO.2
SHIELD_NEO1: J16.SHLD1, J16.SHLD2, J16.SHLD3, J16.SHLD4, SHLD_NEO1.2
SHIELD_NEO2: J26.SHLD1, J26.SHLD2, J26.SHLD3, J26.SHLD4, SHLD_NEO2.2
SHIELD_NEO3: J36.SHLD1, J36.SHLD2, J36.SHLD3, J36.SHLD4, SHLD_NEO3.2
SHIELD_ZED: J3.SHLD1, J3.SHLD2, J3.SHLD3, J3.SHLD4, SHLD_ZED.2
SHIELD_ZED1: J13.SHLD1, J13.SHLD2, J13.SHLD3, J13.SHLD4, SHLD_ZED1.2
SHIELD_ZED2: J23.SHLD1, J23.SHLD2, J23.SHLD3, J23.SHLD4, SHLD_ZED2.2
SHIELD_ZED3: J33.SHLD1, J33.SHLD2, J33.SHLD3, J33.SHLD4, SHLD_ZED3.2
SMA: C7.1, D1.1, FB1.1, J1.SIG, L1.1
SMA1: C18.1, D8.1, FB2.1, J14.SIG, L2.1
SMA2: C29.1, D14.1, FB3.1, J24.SIG, L3.1
SMA3: C40.1, D20.1, FB4.1, J34.SIG, L4.1
TP: J5.6, R25.2, R29.2
TP1: J15.6, R59.2, R63.2
TP2: J25.6, R93.2, R97.2
TP3: J35.6, R127.2, R131.2
TXD1_NEO: J7.3, R3.2
TXD1_NEO1: J20.3, R35.2
TXD1_NEO2: J30.3, R69.2
TXD1_NEO3: J40.3, R103.2
TXD1_ZED: J8.4, R21.2
TXD1_ZED1: J19.4, R55.2
TXD1_ZED2: J29.4, R89.2
TXD1_ZED3: J39.4, R123.2
TXD2_NEO: J7.1, R11.2, RX2-TX2.2
TXD2_NEO1: J20.1, R47.2, RX2-TX1.2
TXD2_NEO2: J30.1, R81.2, RX2-TX3.2
TXD2_NEO3: J40.1, R115.2, RX2-TX4.2
TXD2_ZED: J8.2, R17.2, TX2-RX2.1
TXD2_ZED1: J19.2, R51.2, TX2-RX1.1
TXD2_ZED2: J29.2, R85.2, TX2-RX3.1
TXD2_ZED3: J39.2, R119.2, TX2-RX4.1
TX_RDY: J5.7, R26.2
TX_RDY1: J15.7, R60.2
TX_RDY2: J25.7, R94.2
TX_RDY3: J35.7, R128.2
USB_D+: D2.1, J3.A6, J3.B6
USB_D+1: D4.1, J6.A6, J6.B6
USB_D+2: D7.1, J13.A6, J13.B6
USB_D+3: D10.1, J16.A6, J16.B6
USB_D+4: D13.1, J23.A6, J23.B6
USB_D+5: D16.1, J26.A6, J26.B6
USB_D+6: D19.1, J33.A6, J33.B6
USB_D+7: D22.1, J36.A6, J36.B6
USB_D-: D2.3, J3.A7, J3.B7
USB_D-1: D4.3, J6.A7, J6.B7
USB_D-2: D7.3, J13.A7, J13.B7
USB_D-3: D10.3, J16.A7, J16.B7
USB_D-4: D13.3, J23.A7, J23.B7
USB_D-5: D16.3, J26.A7, J26.B7
USB_D-6: D19.3, J33.A7, J33.B7
USB_D-7: D22.3, J36.A7, J36.B7
VCC_RF: R14.2, U1.9
VCC_RF1: R44.2, U6.9
VCC_RF2: R78.2, U10.9
VCC_RF3: R112.2, U14.9
V_BKCP: BT1.+, R32.1, U4.36, V_BKCP.1
V_BKCP1: BT2.+, R66.1, U8.36, V_BKCP1.1
V_BKCP2: BT3.+, R100.1, U12.36, V_BKCP2.1
V_BKCP3: BT4.+, R134.1, U16.36, V_BKCP3.1
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

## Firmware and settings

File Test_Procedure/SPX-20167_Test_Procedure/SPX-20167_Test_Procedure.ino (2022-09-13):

/*
  u-blox ZED-F9P NEO-D9S Combo Board (SPX-20167) Test Procedure 
  By: Paul Clark
  SparkFun Electronics
  Date: September 2022
  
  Runs on SparkFun Thing Plus - ESP32 WROOM (USB-C) (WRL-20168)
                                  
  License: MIT
  Please see LICENSE.md for more details
  
*/


#define serialQUAD Serial // Use Serial for the Qwiic Universal Auto-Detect menus

// -=-=-=-=-=-=-=-=-=-=-=-=-=-=-=-=-=-=-=-=-=-=-=-=-=-=-=-=-=-=-=-=-=-=-=-=-=-=-=-=-=-=-=-=-=-=-=-=-=-=-=-=-=-=-=-=-=-=-=-=-=-=-=
// Use EEPROM for configuration storage

#include <EEPROM.h> // Include EEPROM.h to enable support for SFE_QUAD_Sensors__EEPROM. Do this before #include "SFE_QUAD_Sensors.h"

#include "SFE_QUAD_Sensors.h" // Click here to get the library:  http://librarymanager/All#SparkFun_Qwiic_Universal_Auto-Detect

SFE_QUAD_Sensors__EEPROM mySensors;

// -=-=-=-=-=-=-=-=-=-=-=-=-=-=-=-=-=-=-=-=-=-=-=-=-=-=-=-=-=-=-=-=-=-=-=-=-=-=-=-=-=-=-=-=-=-=-=-=-=-=-=-=-=-=-=-=-=-=-=-=-=-=-=
// Thing Plus C hardware specifics

int qwiicPower = 0; //Thing Plus C digital pin 0 is connected to the v-reg that controls the Qwiic power. It is also connected to the BOOT button.

#ifndef LED_BUILTIN
#define LED_BUILTIN 13 // The Thing Plus C STAT LED is connected to digital pin 13
#endif

// -=-=-=-=-=-=-=-=-=-=-=-=-=-=-=-=-=-=-=-=-=-=-=-=-=-=-=-=-=-=-=-=-=-=-=-=-=-=-=-=-=-=-=-=-=-=-=-=-=-=-=-=-=-=-=-=-=-=-=-=-=-=-=
// ESP32 WiFi

#include <WiFi.h>
#include <HTTPClient.h>

WiFiClient myClient;

// -=-=-=-=-=-=-=-=-=-=-=-=-=-=-=-=-=-=-=-=-=-=-=-=-=-=-=-=-=-=-=-=-=-=-=-=-=-=-=-=-=-=-=-=-=-=-=-=-=-=-=-=-=-=-=-=-=-=-=-=-=-=-=

const char assistNowServer[] = "https://online-live1.services.u-blox.com";
//const char assistNowServer[] = "https://online-live2.services.u-blox.com"; // Alternate server

const char getQuery[] = "GetOnlineData.ashx?";
const char tokenPrefix[] = "token=";
const char tokenSuffix[] = ";";
const char getGNSS[] = "gnss=gps,glo;"; // GNSS can be: gps,qzss,glo,bds,gal
const char getDataType[] = "datatype=eph,alm,aux;"; // Data type can be: eph,alm,aux,pos

// -=-=-=-=-=-=-=-=-=-=-=-=-=-=-=-=-=-=-=-=-=-=-=-=-=-=-=-=-=-=-=-=-=-=-=-=-=-=-=-=-=-=-=-=-=-=-=-=-=-=-=-=-=-=-=-=-=-=-=-=-=-=-=

//#include <SparkFun_u-blox_GNSS_Arduino_Library.h> //http://librarymanager/All#SparkFun_u-blox_GNSS
SFE_UBLOX_GNSS myGNSS; // ZED-F9P
SFE_UBLOX_GNSS myLBand; // NEO-D9S

//#define USE_MGA_ACKs // Uncomment this line to use the UBX_MGA_ACK_DATA0 acknowledgements

const uint32_t myLBandFreq = 1556290000; // Uncomment this line to use the US SPARTN 1.8 service
//const uint32_t myLBandFreq = 1545260000; // Uncomment this line to use the EU SPARTN 1.8 service

static volatile bool pmpDataSeen = false;

#define OK(ok) (ok ? F("  ->  OK") : F("  ->  ERROR!")) // Convert uint8_t into OK/ERROR

// -=-=-=-=-=-=-=-=-=-=-=-=-=-=-=-=-=-=-=-=-=-=-=-=-=-=-=-=-=-=-=-=-=-=-=-=-=-=-=-=-=-=-=-=-=-=-=-=-=-=-=-=-=-=-=-=-=-=-=-=-=-=-=

// Callback: printRXMPMP will be called when new PMP data arrives
// See u-blox_structs.h for the full definition of UBX_RXM_PMP_data_t
//         _____  You can use any name you like for the callback. Use the same name when you call setRXMPMPcallbackPtr
//        /               _____  This _must_ be UBX_RXM_PMP_data_t
//        |              /              _____ You can use any name you like for the struct
//        |              |             /
//        |              |             |
void printRXMPMP(UBX_RXM_PMP_data_t *pmpData)
{
  serialQUAD.println();
  
  serialQUAD.println(F("New PMP data received:"));

  serialQUAD.print(F("PMP message version: "));
  serialQUAD.println(pmpData->version);
  
  serialQUAD.print(F("numBytesUserData :   "));
  serialQUAD.println(pmpData->numBytesUserData);
  
  serialQUAD.print(F("serviceIdentifier:   "));
  serialQUAD.println(pmpData->serviceIdentifier);
  
  serialQUAD.print(F("uniqueWordBitErrors: "));
  serialQUAD.println(pmpData->uniqueWordBitErrors);
  
  serialQUAD.print(F("fecBits:             "));
  serialQUAD.println(pmpData->fecBits);
  
  serialQUAD.print(F("ebno:                "));
  serialQUAD.println(pmpData->ebno);

  serialQUAD.println();

  pmpDataSeen = true;
}

// -=-=-=-=-=-=-=-=-=-=-=-=-=-=-=-=-=-=-=-=-=-=-=-=-=-=-=-=-=-=-=-=-=-=-=-=-=-=-=-=-=-=-=-=-=-=-=-=-=-=-=-=-=-=-=-=-=-=-=-=-=-=-=

void setup()
{
  serialQUAD.begin(115200);
  delay(1000);

  // Enable power for the Qwiic bus
  // The input pull-up is enough to enable the regulator
  // We can then also use the BOOT button if we want to
  pinMode(qwiicPower, INPUT_PULLUP);

  // Flash LED_BUILTIN each time we test
  pinMode(LED_BUILTIN, OUTPUT);
  digitalWrite(LED_BUILTIN, LOW);

  // -=-=-=-=-=-=-=-=-=-=-=-=-=-=-=-=-=-=-=-=-=-=-=-=-=-=-=-=-=-=-=-=-=-=-=-=
  // Detect, initialize and configure the sensors

  //mySensors.enableDebugging(serialQUAD); // Uncomment this line to enable debug messages on serialQUAD

  mySensors.setMenuPort(serialQUAD); // Use serialQUAD for the logging menu

  mySensors.theMenu.setMenuTimeout(60000); // Set the menu timeout to 60 seconds
  
  if (!mySensors.beginStorage()) // Begin EEPROM storage
    serialQUAD.println(F("beginStorage failed! You will not be able to read or write the sensor configuration..."));

  // -=-=-=-=-=-=-=-=-=-=-=-=-=-=-=-=-=-=-=-=-=-=-=-=-=-=-=-=-=-=-=-=-=-=-=-=
  // Create the menu

  // The Arduino IDE Serial Monitor does not support backspace so - by default - we need to clear text values when editing them.
  // The user enters the entire text value each time.
  // If the user is using a terminal emulator which supports backspace (e.g. Tera Term) then
  // setting supportsBackspace to true will allow the existing text to be edited.
  mySensors.theMenu.setMenuPort(serialQUAD, true); // Uncomment this line to use serialQUAD for the menu - on a terminal emulator which supports backspace

  while (mySensors.theMenu._menuPort->available()) // Clear the menu serial buffer
    mySensors.theMenu._menuPort->read();

  // Create the menu - using unique menu item names.
  // You can duplicate NONE or SUB_MENU_START items (e.g. "Wifi Menu") but all other items must be unique

  mySensors.theMenu.addMenuItem("", SFE_QUAD_MENU_VARIABLE_TYPE_NONE);
  mySensors.theMenu.addMenuItem("SparkFun ZED-F9P NEO-D9S Combo Board Test", SFE_QUAD_MENU_VARIABLE_TYPE_NONE);
  mySensors.theMenu.addMenuItem("=========================================", SFE_QUAD_MENU_VARIABLE_TYPE_NONE);
  mySensors.theMenu.addMenuItem("", SFE_QUAD_MENU_VARIABLE_TYPE_NONE);
  mySensors.theMenu.addMenuItem("", SFE_QUAD_MENU_VARIABLE_TYPE_NONE);
  mySensors.theMenu.addMenuItem("Test a board", testTheBoard);
  mySensors.theMenu.addMenuItem("", SFE_QUAD_MENU_VARIABLE_TYPE_NONE);
  mySensors.theMenu.addMenuItem("", SFE_QUAD_MENU_VARIABLE_TYPE_NONE);
  mySensors.theMenu.addMenuItem("Connect to WiFi", wifiConnect);
  mySensors.theMenu.addMenuItem("", SFE_QUAD_MENU_VARIABLE_TYPE_NONE);
  mySensors.theMenu.addMenuItem("", SFE_QUAD_MENU_VARIABLE_TYPE_NONE);
  mySensors.theMenu.addMenuItem("Write the configuration to EEPROM", writeLoggerConfig);
  mySensors.theMenu.addMenuItem("Read the configuration from EEPROM", readLoggerConfig);
  mySensors.theMenu.addMenuItem("", SFE_QUAD_MENU_VARIABLE_TYPE_NONE);

  // WiFi sub-menu: set the WiFi SSID and password
  mySensors.theMenu.addMenuItem("WiFi Menu", SFE_QUAD_MENU_VARIABLE_TYPE_SUB_MENU_START); // Start of the WiFi sub-menu
  mySensors.theMenu.addMenuItem("", SFE_QUAD_MENU_VARIABLE_TYPE_NONE);
  mySensors.theMenu.addMenuItem("WiFi Menu", SFE_QUAD_MENU_VARIABLE_TYPE_NONE);
  mySensors.theMenu.addMenuItem("=========", SFE_QUAD_MENU_VARIABLE_TYPE_NONE);
  mySensors.theMenu.addMenuItem("", SFE_QUAD_MENU_VARIABLE_TYPE_NONE);
  mySensors.theMenu.addMenuItem("WiFi SSID", SFE_QUAD_MENU_VARIABLE_TYPE_TEXT);
  mySensors.theMenu.setMenuItemVariable("WiFi SSID", "sparkfun-guest"); // Set the default SSID - this will be updated by readLoggerConfig
  mySensors.theMenu.addMenuItem("WiFi password", SFE_QUAD_MENU_VARIABLE_TYPE_TEXT);
  mySensors.theMenu.setMenuItemVariable("WiFi password", "sparkfun6333"); // Set the default password - this will be updated by readLoggerConfig
  mySensors.theMenu.addMenuItem("", SFE_QUAD_MENU_VARIABLE_TYPE_NONE);
  mySensors.theMenu.addMenuItem("Connect to WiFi", wifiConnect);
  mySensors.theMenu.addMenuItem("", SFE_QUAD_MENU_VARIABLE_TYPE_NONE);
  mySensors.theMenu.addMenuItem("", SFE_QUAD_MENU_VARIABLE_TYPE_SUB_MENU_END); // End of the WiFi sub-menu
  
  // Thingstream PointPerfect AssistNow sub-menu: set the AssistNow Token
  mySensors.theMenu.addMenuItem("AssistNow Menu", SFE_QUAD_MENU_VARIABLE_TYPE_SUB_MENU_START);
  mySensors.theMenu.addMenuItem("", SFE_QUAD_MENU_VARIABLE_TYPE_NONE);
  mySensors.theMenu.addMenuItem("AssistNow Menu", SFE_QUAD_MENU_VARIABLE_TYPE_NONE);
  mySensors.theMenu.addMenuItem("============", SFE_QUAD_MENU_VARIABLE_TYPE_NONE);
  mySensors.theMenu.addMenuItem("", SFE_QUAD_MENU_VARIABLE_TYPE_NONE);
  mySensors.theMenu.addMenuItem("AssistNow Token", SFE_QUAD_MENU_VARIABLE_TYPE_TEXT);
  mySensors.theMenu.setMenuItemVariable("AssistNow Token", "6AcdNZtqRhqwI1-6u7hX4g"); // Set the default AssistNow Token - this will be updated by readLoggerConfig
  mySensors.theMenu.addMenuItem("", SFE_QUAD_MENU_VARIABLE_TYPE_NONE);
  mySensors.theMenu.addMenuItem("", SFE_QUAD_MENU_VARIABLE_TYPE_SUB_MENU_END); // End of the sub-menu

  // Thingstream PointPerfect L-Band sub-menu: set the L-Band Key
  mySensors.theMenu.addMenuItem("PointPerfect L-Band Menu", SFE_QUAD_MENU_VARIABLE_TYPE_SUB_MENU_START);
  mySensors.theMenu.addMenuItem("", SFE_QUAD_MENU_VARIABLE_TYPE_NONE);
  mySensors.theMenu.addMenuItem("PointPerfect L-Band Menu", SFE_QUAD_MENU_VARIABLE_TYPE_NONE);
  mySensors.theMenu.addMenuItem("============", SFE_QUAD_MENU_VARIABLE_TYPE_NONE);
  mySensors.theMenu.addMenuItem("", SFE_QUAD_MENU_VARIABLE_TYPE_NONE);
  mySensors.theMenu.addMenuItem("L-Band Dynamic Key", SFE_QUAD_MENU_VARIABLE_TYPE_TEXT);
  mySensors.theMenu.setMenuItemVariable("L-Band Dynamic Key", "5002d290058c8c24ed00635144d53177"); // Set the default L-Band Token - this will be updated by readLoggerConfig
  mySensors.theMenu.addMenuItem("Valid From GPS Week", SFE_QUAD_MENU_VARIABLE_TYPE_UINT16_T);
  SFE_QUAD_Menu_Every_Type_t defaultValue;
  defaultValue.UINT16_T = 2224; // Valid from August 27th 2022. Expires: 23:59 (UTC) Sep 23, 2022
  mySensors.theMenu.setMenuItemVariable("Valid From GPS Week", &defaultValue); // Set the default valid from week no.
  mySensors.theMenu.addMenuItem("", SFE_QUAD_MENU_VARIABLE_TYPE_NONE);
  mySensors.theMenu.addMenuItem("", SFE_QUAD_MENU_VARIABLE_TYPE_SUB_MENU_END); // End of the sub-menu

  
  mySensors.theMenu.addMenuItem("", SFE_QUAD_MENU_VARIABLE_TYPE_NONE);
  // End of the menu

  // -=-=-=-=-=-=-=-=-=-=-=-=-=-=-=-=-=-=-=-=-=-=-=-=-=-=-=-=-=-=-=-=-=-=-=-=
  // Read the configuration file, configure the sensors and update the menu variables. Do this _after_ the menu has been created.

  readLoggerConfig();

} // /setup()

// -=-=-=-=-=-=-=-=-=-=-=-=-=-=-=-=-=-=-=-=-=-=-=-=-=-=-=-=-=-=-=-=-=-=-=-=-=-=-=-=-=-=-=-=-=-=-=-=-=-=-=-=-=-=-=-=-=-=-=-=-=-=-=

void loop()
{
  // -=-=-=-=-=-=-=-=-=-=-=-=-=-=-=-=-=-=-=-=-=-=-=-=-=-=-=-=-=-=-=-=-=-=-=-=
  // Menu
  
//  if (mySensors.theMenu._menuPort->available()) // Has the user pressed a key?
//  {
    mySensors.theMenu.openMenu(); // If so, open the menu
//  }
} // /loop()


// -=-=-=-=-=-=-=-=-=-=-=-=-=-=-=-=-=-=-=-=-=-=-=-=-=-=-=-=-=-=-=-=-=-=-=-=-=-=-=-=-=-=-=-=-=-=-=-=-=-=-=-=-=-=-=-=-=-=-=-=-=-=-=

// Do the test
void testTheBoard(void)
{
  if (WiFi.status() != WL_CONNECTED)
  {
    serialQUAD.println("You are not connected to WiFi! Please connect and then try again...");
    return;
  }

  char myAssistNowToken[33];
  mySensors.theMenu.getMenuItemVariable("AssistNow Token", myAssistNowToken, 33);

  //=-=-=-=-=-=-=-=-=-=-=-=-=-=-=-=-=-=-=-=-=-=-=-=-=-=-=-=-=-=-=-=-=-=-=-=-=-=-=-=-=-=-=-=-=
  // Start I2C. Connect to the GNSS.

  Wire.begin(); //Start I2C

  if (myGNSS.begin() == false) //Connect to the Ublox module using Wire port
  {
    serialQUAD.println(F("u-blox ZED-F9P not detected. Please check wiring. Test Failed."));
    return;
  }
  
  serialQUAD.println(F("u-blox ZED-F9P connected"));

  myGNSS.setI2COutput(COM_TYPE_UBX); //Turn off NMEA noise
  myGNSS.setPortInput(COM_PORT_UART2, COM_TYPE_UBX | COM_TYPE_NMEA | COM_TYPE_SPARTN); //Be sure SPARTN input is enabled
  myGNSS.setDGNSSConfiguration(SFE_UBLOX_DGNSS_MODE_FIXED); // Set the differential mode - ambiguities are fixed whenever possible
  myGNSS.setVal8(UBLOX_CFG_SPARTN_USE_SOURCE, 1); // use LBAND PMP message

  //=-=-=-=-=-=-=-=-=-=-=-=-=-=-=-=-=-=-=-=-=-=-=-=-=-=-=-=-=-=-=-=-=-=-=-=-=-=-=-=-=-=-=-=-=
  // Use HTTP GET to receive the AssistNow_Online data

  const int URL_BUFFER_SIZE  = 256;
  char theURL[URL_BUFFER_SIZE]; // This will contain the HTTP URL
  int payloadSize = 0; // This will be updated with the length of the data we get from the server
  String payload; // This will store the data we get from the server

  // Assemble the URL
  // Note the slash after the first %s (assistNowServer)
  snprintf(theURL, URL_BUFFER_SIZE, "%s/%s%s%s%s%s%s",
    assistNowServer,
    getQuery,
    tokenPrefix,
    myAssistNowToken,
    tokenSuffix,
    getGNSS,
    getDataType);

  HTTPClient http;

  http.begin(theURL);

  int httpCode = http.GET(); // HTTP GET

  // httpCode will be negative on error
  if(httpCode > 0)
  {
    // HTTP header has been sent and Server response header has been handled
    serialQUAD.printf("[HTTP] GET... code: %d\r\n", httpCode);
  
    // If the GET was successful, read the data
    if(httpCode == HTTP_CODE_OK) // Check for code 200
    {
      payloadSize = http.getSize();
      serialQUAD.printf("Server returned %d bytes\r\n", payloadSize);
      
      payload = http.getString(); // Get the payload
    }
  }
  else
  {
    serialQUAD.printf("[HTTP] GET... failed, error: %s\r\n", http.errorToString(httpCode).c_str());
  }
  
  http.end();  
  
  //=-=-=-=-=-=-=-=-=-=-=-=-=-=-=-=-=-=-=-=-=-=-=-=-=-=-=-=-=-=-=-=-=-=-=-=-=-=-=-=-=-=-=-=-=
  // Push the AssistNow data to the module

  if (payloadSize > 0)
  {  
    // Uncomment the next line to enable the 'major' debug messages on Serial so you can see what AssistNow data is being sent
    //myGNSS.enableDebugging(Serial, true);

#ifndef USE_MGA_ACKs

    // ***** Don't use the UBX_MGA_ACK_DATA0 messages *****

    // Push all the AssistNow data. Don't use UBX_MGA_ACK_DATA0's. Use the default delay of 7ms between messages.
    myGNSS.pushAssistNowData(payload, (size_t)payloadSize);

#else

    // ***** Use the UBX_MGA_ACK_DATA0 messages *****

    // Tell the module to return UBX_MGA_ACK_DATA0 messages when we push the AssistNow data
    myGNSS.setAckAiding(1);

    // Speed things up by setting setI2CpollingWait to 1ms
    myGNSS.setI2CpollingWait(1);

    // Push all the AssistNow data.
    // We have called setAckAiding(1) to instruct the module to return MGA-ACK messages.
    // So, we could set the pushAssistNowData mgaAck parameter to SFE_UBLOX_MGA_ASSIST_ACK_YES.
    // But, just for giggles, let's use SFE_UBLOX_MGA_ASSIST_ACK_ENQUIRE just to confirm that the
    // MGA-ACK messages are actually enabled.
    // Wait for up to 100ms for each ACK to arrive! 100ms is a bit excessive... 7ms is nearer the mark.
    myGNSS.pushAssistNowData(payload, (size_t)payloadSize, SFE_UBLOX_MGA_ASSIST_ACK_ENQUIRE, 100);

    // Set setI2CpollingWait to 125ms to avoid pounding the I2C bus
    myGNSS.setI2CpollingWait(125);

#endif

  }

  //=-=-=-=-=-=-=-=-=-=-=-=-=-=-=-=-=-=-=-=-=-=-=-=-=-=-=-=-=-=-=-=-=-=-=-=-=-=-=-=-=-=-=-=-=
  // Wait for up to 20 seconds for the fix type to be 3D

  serialQUAD.print(F("Waiting for a 3D fix"));
  
  unsigned long startTime = millis();
  byte fixType = 0;

  while ((fixType != 3) && (millis() < (startTime + 20000)))
  {
    delay(500);
    
    serialQUAD.print(F("."));

    fixType = myGNSS.getFixType();
  }

  serialQUAD.println();

  if (fixType != 3)
  {
    serialQUAD.println(F("Could not get a 3D fix. Test failed."));
    return;
  }

  serialQUAD.println(F("Got a 3D Fix!"));

  serialQUAD.println();

  serialQUAD.println(F("Please check that the TP LED is flashing. Please fail the board if not."));

  serialQUAD.println();

  //=-=-=-=-=-=-=-=-=-=-=-=-=-=-=-=-=-=-=-=-=-=-=-=-=-=-=-=-=-=-=-=-=-=-=-=-=-=-=-=-=-=-=-=-=
  // Configure the SPARTN IP Dynamic Keys
  // "When the receiver boots, the host should send 'current' and 'next' keys in one message." - Use setDynamicSPARTNKeys for this.
  // "Every time the 'current' key is expired, 'next' takes its place."
  // "Therefore the host should then retrieve the new 'next' key and send only that." - Use setDynamicSPARTNKey for this.
  // The key can be provided in binary (uint8_t) format or in ASCII Hex (char) format, but in both cases keyLengthBytes _must_ represent the binary key length in bytes.

  char currentDynamicKey[33];
  mySensors.theMenu.getMenuItemVariable("L-Band Dynamic Key", currentDynamicKey, 33);

  SFE_QUAD_Menu_Every_Type_t currentKeyGPSWeek;
  mySensors.theMenu.getMenuItemVariable("Valid From GPS Week", &currentKeyGPSWeek); // Get the currentKeyGPSWeek

  const uint8_t currentKeyLengthBytes =   16; 
  const uint32_t currentKeyGPSToW =       518400;

  myGNSS.setDynamicSPARTNKey(currentKeyLengthBytes, currentKeyGPSWeek.UINT16_T, currentKeyGPSToW, currentDynamicKey);

  //=-=-=-=-=-=-=-=-=-=-=-=-=-=-=-=-=-=-=-=-=-=-=-=-=-=-=-=-=-=-=-=-=-=-=-=-=-=-=-=-=-=-=-=-=
  // Begin and configure the NEO-D9S L-Band receiver

  //myLBand.enableDebugging(); // Uncomment this line to enable helpful debug messages on Serial

  while (myLBand.begin(Wire, 0x43) == false) //Connect to the u-blox NEO-D9S using Wire port. The D9S default I2C address is 0x43 (not 0x42)
  {
    serialQUAD.println(F("u-blox NEO-D9S not detected. Please check wiring. Test Failed."));
    return;
  }
  serialQUAD.println(F("u-blox NEO-D9S connected"));

  uint8_t ok = myLBand.setVal32(UBLOX_CFG_PMP_CENTER_FREQUENCY,   myLBandFreq); // Default 1539812500 Hz
  if (ok) ok = myLBand.setVal16(UBLOX_CFG_PMP_SEARCH_WINDOW,      2200);        // Default 2200 Hz
  if (ok) ok = myLBand.setVal8(UBLOX_CFG_PMP_USE_SERVICE_ID,      0);           // Default 1 
  if (ok) ok = myLBand.setVal16(UBLOX_CFG_PMP_SERVICE_ID,         21845);       // Default 50821
  if (ok) ok = myLBand.setVal16(UBLOX_CFG_PMP_DATA_RATE,          2400);        // Default 2400 bps
  if (ok) ok = myLBand.setVal8(UBLOX_CFG_PMP_USE_DESCRAMBLER,     1);           // Default 1
  if (ok) ok = myLBand.setVal16(UBLOX_CFG_PMP_DESCRAMBLER_INIT,   26969);       // Default 23560
  if (ok) ok = myLBand.setVal8(UBLOX_CFG_PMP_USE_PRESCRAMBLING,   0);           // Default 0
  if (ok) ok = myLBand.setVal64(UBLOX_CFG_PMP_UNIQUE_WORD,        16238547128276412563ull); 
  if (ok) ok = myLBand.setVal(UBLOX_CFG_MSGOUT_UBX_RXM_PMP_I2C,   1); // Ensure UBX-RXM-PMP is enabled on the I2C port 
  if (ok) ok = myLBand.setVal(UBLOX_CFG_MSGOUT_UBX_RXM_PMP_UART1, 1); // Output UBX-RXM-PMP on UART1
  if (ok) ok = myLBand.setVal(UBLOX_CFG_UART2OUTPROT_UBX, 1);         // Enable UBX output on UART2
  if (ok) ok = myLBand.setVal(UBLOX_CFG_MSGOUT_UBX_RXM_PMP_UART2, 1); // Output UBX-RXM-PMP on UART2
  if (ok) ok = myLBand.setVal32(UBLOX_CFG_UART1_BAUDRATE,         38400); // match baudrate with ZED default
  if (ok) ok = myLBand.setVal32(UBLOX_CFG_UART2_BAUDRATE,         38400); // match baudrate with ZED default

  serialQUAD.print(F("L-Band: configuration "));
  serialQUAD.println(OK(ok));

  myLBand.softwareResetGNSSOnly(); // Do a restart

  myLBand.setRXMPMPcallbackPtr(&printRXMPMP); // Call printRXMPMP when new PMP data arrives

  //=-=-=-=-=-=-=-=-=-=-=-=-=-=-=-=-=-=-=-=-=-=-=-=-=-=-=-=-=-=-=-=-=-=-=-=-=-=-=-=-=-=-=-=-=
  // Wait for up to 20 seconds PMP data to arrive

  serialQUAD.print(F("Waiting for PMP data"));
  
  startTime = millis();
  pmpDataSeen = false;

  while ((!pmpDataSeen) && (millis() < (startTime + 20000)))
  {
    serialQUAD.print(F("."));

    myLBand.checkUblox(); // Check for the arrival of new PMP data and process it.
    myLBand.checkCallbacks(); // Check if any LBand callbacks are waiting to be processed.

    if (!pmpDataSeen)
      delay(500);
  }

  serialQUAD.println();

  if (!pmpDataSeen)
  {
    serialQUAD.println(F("No PMP data received. Test failed."));
    return;
  }

  //=-=-=-=-=-=-=-=-=-=-=-=-=-=-=-=-=-=-=-=-=-=-=-=-=-=-=-=-=-=-=-=-=-=-=-=-=-=-=-=-=-=-=-=-=

  serialQUAD.println(F("If the L-Band Dynamic Key is valid, and you have a good L-Band signal, the NEO will be pushing corrections to the ZED."));
  serialQUAD.println();
  serialQUAD.println(F("If you see the RTK LED flash, you have a FLOAT solution. That's an excellent thing!"));
  serialQUAD.println();
  serialQUAD.println(F("If the RTK LED stays on continuously (on the x02 PCB) then you have a FIXED solution. That's a _really_ excellent thing!"));

  serialQUAD.println();
  serialQUAD.println();

  serialQUAD.println(F("Please measure the voltage of the back-up battery. Measure between the top of the battery and GND. It should be around 2.5V."));

  serialQUAD.println();
  serialQUAD.println();

  serialQUAD.println(F("If the battery voltage is OK - TEST PASSED!"));

  serialQUAD.println();

}
        
// -=-=-=-=-=-=-=-=-=-=-=-=-=-=-=-=-=-=-=-=-=-=-=-=-=-=-=-=-=-=-=-=-=-=-=-=-=-=-=-=-=-=-=-=-=-=-=-=-=-=-=-=-=-=-=-=-=-=-=-=-=-=-=

// Read the configuration, configure the sensors and update the menu variables
void readLoggerConfig(void)
{
  bool success = mySensors.readConfigurationFromStorage();
  success &= mySensors.applySensorAndMenuConfiguration();
  if (success)
    serialQUAD.println(F("Configuration read from EEPROM"));
  else
    serialQUAD.println(F("Unable to read configuration from EEPROM"));
}

// -=-=-=-=-=-=-=-=-=-=-=-=-=-=-=-=-=-=-=-=-=-=-=-=-=-=-=-=-=-=-=-=-=-=-=-=-=-=-=-=-=-=-=-=-=-=-=-=-=-=-=-=-=-=-=-=-=-=-=-=-=-=-=
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

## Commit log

2022-05-26 x01 PCB
    [ZED-F9P_NEO-D9S_Combo-Panel.GBL, ZED-F9P_NEO-D9S_Combo-Panel.GBO, ZED-F9P_NEO-D9S_Combo-Panel.GBP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]
2022-05-26 Add IC-16658 GNSS Power Divider. Delete New_parts.lbr
    [ZED-F9P_NEO-D9S_Combo-Panel.brd, ZED-F9P_NEO-D9S_Combo.brd, ZED-F9P_NEO-D9S_Combo.sch]
2022-05-26 Use RF Library copy of IC-16658
    [ZED-F9P_NEO-D9S_Combo-Panel.brd, ZED-F9P_NEO-D9S_Combo.brd, ZED-F9P_NEO-D9S_Combo.sch]
2022-07-20 x02 PCB - inverts RTK LED
    [ZED-F9P_NEO-D9S_Combo-Panel.brd, ZED-F9P_NEO-D9S_Combo.brd, ZED-F9P_NEO-D9S_Combo.sch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]
2023-01-25 Add new 10m SMA cable

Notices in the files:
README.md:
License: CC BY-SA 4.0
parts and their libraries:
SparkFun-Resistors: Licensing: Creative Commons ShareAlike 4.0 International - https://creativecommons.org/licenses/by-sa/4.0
